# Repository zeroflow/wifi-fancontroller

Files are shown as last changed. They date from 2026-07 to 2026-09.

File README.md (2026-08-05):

# WiFi Fan Controller

**Smart fan control for your Home Assistant setup**

A CE-certified, ESP32-based PWM fan controller designed for home server racks, media cabinets, and smart home projects. Control up to 4 fans with temperature-based automation, remote monitoring, and seamless Home Assistant integration.

WiFi Fan Controller Board

## Why This Fan Controller?

**Intelligent Climate Control**: Automatically adjust fan speeds based on temperature and humidity readings from the integrated HDC1080 sensor. Turn fans off when equipment is idle, ramp up when things heat up.

**Home Assistant Native**: Built on ESPHome for seamless integration with Home Assistant. Monitor temperatures, adjust fan speeds, and create automations directly from your smart home dashboard.

**Hackable & Expandable**: Fully customizable ESPHome configuration with Qwiic and I2C expansion ports, NeoPixel output, user buttons, and GPIO breakouts. Add sensors, displays, or integrate with your existing projects.

**Professional Quality**: CE certified hardware with RGB status LEDs showing system status at a glance. Standard 12V DC barrel jack power input (5.5x2.1mm, centre positive).

## Get Your Board

**Ready to upgrade your setup?**

**[Buy on Elecrow - $35.99](https://www.elecrow.com/wifi-fancontroller1.html)** - Boards and 3D-printed cases available

**[Complete Documentation & Web Installer](https://fancontroller.arthofer.dev/)** - Flash firmware directly from your browser

**DIY Case**: Print your own case using the [WiFi Fancontroller Case](https://www.printables.com/model/987263-wifi-fancontroller-case) design on Printables.com.

## Power supply

The Fancontroller requires an external 12 V DC SELV power supply, not included.

* **Connector:** 5.5 × 2.1 mm barrel jack, centre positive
* **Voltage:** 12 V DC ±5 %
* **Current:** minimum 2.5 A recommended, depending on fan load

The power supply is not part of the product. Users must supply a power source that is certified for their region.

## RF exposure

This product contains a radio transmitter. Install the product so that a separation distance of at least 20 cm is maintained between the antenna and any person during normal operation. This product is not intended to be worn on the body or operated in close proximity to the user.

## User buttons

The board provides three user-assignable push buttons connected to GPIO. They have no function in the default configuration. Any behaviour is defined by the user's ESPHome configuration. Typical use is setup, commissioning, or occasional manual override; regular operation is via the network interface.

In the factory firmware the buttons are exposed to Home Assistant as binary sensors reporting their pressed state. They trigger no action on the board itself unless you configure one. See the [USR Buttons module](https://fancontroller.arthofer.dev/reference/modules/usr-buttons/) for one ready-made way to assign them.

## Specifications

* **Power**
  * External 12V DC SELV power supply, not included (see [Power supply](#power-supply))
  * 12V DC Barrel Input (5.5x2.1mm, centre positive)
  * Max total input current: 2.5A (set by the DC barrel jack -- applies to the sum of all fans plus board load, not per fan header)
  * Size your supply to the combined draw of the fans you connect, with headroom
  * Low power operation: 0.25W typical, 0.07W deep sleep
* **Fan Control**
  * 4× PWM Fan Outputs with RPM monitoring
  * Supports standard 12V 4-pin PWM fans
* **Sensors & I/O**
  * Integrated HDC1080 Temperature & Humidity Sensor
  * RGB Status LEDs for board and fan ports (Rev 3.x)
  * [Qwiic](https://www.sparkfun.com/qwiic) Expansion Port for easy sensor additions
  * I2C Expansion Port (2.54mm Header)
  * 5V NeoPixel Output Port
  * 3 User Buttons for custom functions
  * GPIO Expansion Pads (2.54mm SMD Header)
* **Connectivity**
  * WiFi (ESP32/ESP32-S2)
  * USB-C for programming and power (Rev 2.0+)

## Power Draw

The power usage of the device is dominated by the fans.
As a standalone device, these are the measured power figures in different operation modes.

Mode | Power Draw
---- | ----------
Active Wifi Transfer (e.g. OTA Upload) | 0.6W
Wifi connected, power save mode deactivated (not default) | 0.52W
```Default``` Wifi connected, LEDs showing status (one-colored) | 0.25W
Wifi connected, LEDs off | 0.2W
Deep Sleep | 0.07W

Disabling Wifi while not in deep sleep does not reduce power consumption, as the default light power save mode already does a good job.

These values have been measured via a DPS3005 power supply, therefore, their accuracy cannot be guaranteed.

---

## Quick Start

All boards come pre-flashed with an ESPHome factory image that's ready to use:

1. **Power up the board** via USB-C or 12V DC (USB-C is for flashing only, power via 12V DC barrel jack is required for fans)
2. **Connect to the WiFi hotspot** (e.g. `fancontroller-r3-1-abcdef`)
3. **Configure your WiFi** through the captive portal
4. **Done!** Board appears in Home Assistant via ESPHome

**What you get out of the box:**
The factory firmware exposes all 4 fan channels as speed controls in Home Assistant, along with temperature and humidity readings from the onboard sensor. Fan speeds can be adjusted manually from 0–100% or automated via Home Assistant. RPM monitoring is available for each fan port.

For custom firmware or troubleshooting, see [Installation Methods](#installation-methods) below.

### Identifying Your Board Revision

To choose the correct firmware, identify your board revision using the connectors:

Revision | Left                      | Fan Ports             | Right   | Details | Notes
---- | ----------------------------- | --------------------- | ------- | ------- | ------
1.0  | DC 12V                        | Fans                  | nothing | [Link](https://fancontroller.arthofer.dev/reference/hardware/rev-1-0/) |
2.0  | DC 12V, Status LED            | Fans                  | USB-C   | [Link](https://fancontroller.arthofer.dev/reference/hardware/rev-2-0/) |
3.0  | DC 12V, Status LED, QWIIC     | Fans                  | USB-C   | [Link](https://fancontroller.arthofer.dev/reference/hardware/rev-3-0/) |
3.1  | DC 12V, RGB Status LED, QWIIC | Fans, RGB Status LEDs | USB-C   | [Link](https://fancontroller.arthofer.dev/reference/hardware/rev-3-x/) |
3.2  | DC 12V, RGB Status LED, QWIIC | Fans, RGB Status LEDs | USB-C   | [Link](https://fancontroller.arthofer.dev/reference/hardware/rev-3-x/) | Compatible firmware and pinout - hardware-only revisions
3.3  | DC 12V, RGB Status LED, QWIIC | Fans, RGB Status LEDs | USB-C   | [Link](https://fancontroller.arthofer.dev/reference/hardware/rev-3-x/) | Compatible firmware and pinout - hardware-only revisions

---

## Installation Methods

### Method 1: Web Installer (Recommended)

Flash pre-built firmware directly from your browser at **[fancontroller.arthofer.dev](https://fancontroller.arthofer.dev/)**

Note for ESP32-S2 boards (Rev 2.0, 3.x): Web-based flashing may have connectivity issues. The most reliable web tool is [ESPWEBTOOL by Spacehuhn](https://esptool.spacehuhn.com/). If the browser flash fails, use Method 2 (esptool) instead.

### Method 2: esptool (Alternative for ESP32-S2)

Reliable flashing method, especially for ESP32-S2 boards:

1. Install [esptool](https://github.com/espressif/esptool): `pip install esptool`
2. Download prebuilt binary from [GitHub Releases](https://github.com/zeroflow/wifi-fancontroller/releases/)
3. Connect board via USB-C, hold BOOT button, press RESET
4. Flash: `esptool.py --chip esp32s2 write_flash 0x0 firmware.bin`
5. Press RESET to boot

### Method 3: OTA Updates (After Initial Setup)

Once connected to WiFi, update wirelessly via ESPHome dashboard or web interface at `http://[board-ip]`

### Method 4: ESPHome Hardware Packages (Custom Configurations)

For users who want to customize their configuration while keeping hardware setup simple. The hardware packages automatically configure all board-specific features for your revision.

This works by adding the following lines to your esphome config:

```yaml
# Import the hardware package for your board revision
packages:
  fancontroller: github://zeroflow/wifi-fancontroller/hardware-rev-3.3.yaml@main
```

#### Example Configuration

Here's a complete example showing how to create a custom configuration using the hardware package:

```yaml
# Import the hardware package for your board revision
packages:
  fancontroller: github://zeroflow/wifi-fancontroller/hardware-rev-3.3.yaml@main

esphome:
  name: my-fancontroller
  friendly_name: My Fan Controller

esp32:
  board: esp32-s2-saola-1  # Use esp32dev for Rev 1.0
  framework:
    type: arduino

# Enable logging
logger:

# Enable Home Assistant API
api:

# Enable OTA updates
ota:
  - platform: esphome

# Configure your WiFi
wifi:
  ssid: !secret wifi_ssid
  password: !secret wifi_password

  # Enable fallback hotspot
  ap: {}

captive_portal:
```

#### Available hardware packages:

- **Rev 1.0:** `hardware-rev-1.0.yaml` (ESP32, esp32dev board)
- **Rev 2.0:** `hardware-rev-2.0.yaml` (ESP32-S2, esp32-s2-saola-1 board)
- **Rev 3.0:** `hardware-rev-3.0.yaml` (ESP32-S2, esp32-s2-saola-1 board)
- **Rev 3.1, 3.2, 3.3:** `hardware-rev-3.3.yaml` (ESP32-S2, esp32-s2-saola-1 board)

#### What's Included in Hardware Packages

The hardware package automatically configures all board features:
- 4× PWM fan outputs with speed control and RPM monitoring
- HDC1080 temperature & humidity sensor
- User buttons (USR1, USR2, USR3) for custom functions
- Status LEDs (RGB on Rev 3.x)
- NeoPixel output port (Rev 3.x)
- WiFi signal strength sensor
- All expansion ports and GPIO

No manual pin configuration needed - just import the package and customize your automations!

---

<details>
<summary><strong>Fan Control Modules (advanced - click to expand)</strong></summary>

## Fan Control Modules

Beyond the basic hardware configuration, this project includes optional control modules that implement different fan control strategies. These modules can be imported into your configuration to add temperature-based fan control or status displays.

### Available Modules

#### 1. RPM Status LEDs (`modules/rpm_status_leds.yaml`)

Visual feedback module that updates each fan's RGB LED based on its RPM reading. LEDs sweep hue from red (stopped) through orange and yellow to green (full speed) using HSV color rotation, keeping the LED at full brightness at every point for vivid, easy-to-read colors.

**Configuration Variables:**
- `full_rpm`: Maximum RPM for color scaling (default: 2500). At 0 RPM = red, at full_rpm = green
- `brightness`: LED brightness 0.0–1.0 (default: 0.5)
- `update_interval`: LED update frequency (default: 1s)
- `fan1_led_enabled` … `fan4_led_enabled`: Enable/disable each LED individually (default: true)

**Example:**
```yaml
packages:
  rpm_status_leds:
    url: https://github.com/zeroflow/wifi-fancontroller
    ref: main
    files:
      - path: modules/rpm_status_leds.yaml
        vars:
          full_rpm: "2500"           # RPM value considered as 100% speed
          brightness: "0.3"          # Adjust for your environment
          fan3_led_enabled: "false"  # disable LED for unused fan channels
          fan4_led_enabled: "false"
```

#### 2. Linear Temperature Control (`modules/temperature_linear.yaml`)

Simple linear fan control based on temperature. Creates a temperature curve with three zones:
- Below t_off: Fans off (0%)
- Between t_off and t1: Constant speed at fanpercent1
- Between t1 and t2: Linear ramp from fanpercent1 to fanpercent2
- Above t2: Constant speed at fanpercent2

**Configuration Variables:**
- `friendly_name`: Device name prefix (default: "fancontroller")
- `t_off`: Temperature below which fans turn off (default: 25.0°C)
- `t1`: Lower temperature setpoint (default: 30.0°C)
- `t2`: Upper temperature setpoint (default: 50.0°C)
- `fanpercent1`: Fan speed % at t1 (default: 30.0%)
- `fanpercent2`: Fan speed % at t2 and above (default: 100.0%)

**Features:**
- Individual auto-control switches for each of 4 fans
- Output value sensor showing current calculated fan speed

**Example:**
```yaml
packages:
  temperature_linear:
    url: https://github.com/zeroflow/wifi-fancontroller
    files: 
      - path: modules/temperature_linear.yaml
        vars:
          friendly_name: "Server Rack"
          t_off: "25.0"        # Fans off below 25°C
          t1: "30.0"           # Start ramping at 30°C
          t2: "50.0"           # Full speed at 50°C
          fanpercent1: "30.0"  # Minimum speed: 30%
          fanpercent2: "100.0" # Maximum speed: 100%
```

#### 3. PID Temperature Control (`modules/temperature_pid.yaml`)

Advanced PID (Proportional-Integral-Derivative) control for precise temperature regulation. Automatically adjusts fan speeds to maintain a target temperature with minimal overshoot.

Shoutout to [patrickcollins12/esphome-fan-controller](https://github.com/patrickcollins12/esphome-fan-controller) for the example code.

A PID simulator is available at https://fancontroller.arthofer.dev/pid-simulator.
It uses simplified thermal models - treat results as a starting point for tuning.

**Configuration Variables:**
- `friendly_name`: Device name prefix (default: "fancontroller")
- `kp`: Proportional gain coefficient (default: 0.39509)
- `ki`: Integral gain coefficient (default: 0.00470)
- `kd`: Derivative gain coefficient (default: 20.74267)
- `max_integral`: Maximum integral term value (default: 0.0)
- `output_averaging_samples`: Output averaging samples (default: 1)
- `derivative_averaging_samples`: Derivative averaging samples (default: 5)

**Features:**
- Climate entity (thermostat) for Home Assistant integration
- Live PID tuning via Home Assistant number entities
- Auto-tune button for automatic PID parameter calculation
- Deadband control to reduce oscillation near target
- Manual override fan control
- Individual PID control switches for each of 4 fans
- Real-time monitoring of P, I, D terms and error values

**Example:**
```yaml
packages:
  temperature_pid:
    url: https://github.com/zeroflow/wifi-fancontroller
    files:
      - path: modules/temperature_pid.yaml
        vars:
          friendly_name: "Server Rack"
          kp: "0.39509"
          ki: "0.00470"
          kd: "20.74267"

```

**Tuning Tips:**
- Use the "PID Climate Autotune" button for automatic tuning
- Start with low kp/ki/kd values and increase gradually
- Monitor the P/I/D term sensors to understand controller behavior

#### 4. RPM PI Control (`modules/rpm_pi_control.yaml`)

PI (Proportional-Integral) controller that regulates PWM output to achieve and maintain precise target RPM for each fan. Unlike percentage-based control, this module uses closed-loop feedback to compensate for fan aging, voltage variations, and load changes.

**Important:** This module uses the existing fan speed sensors from the hardware package. Since the default hardware sensors update every 10s with heavy filtering (too slow for stable PI control), you **must override** the sensor definitions in your config to use faster updates (2s recommended) and minimal filtering. See the example configuration below.

**Configuration Variables:**
- `friendly_name`: Device name prefix (default: "fancontroller")
- `kp`: Proportional gain coefficient (default: 0.005)
- `ki`: Integral gain coefficient (default: 0.001)
- `update_interval`: Control loop update interval in seconds (default: 2, matches fast sensor update)

**Features:**
- Individual target RPM setpoints for each of 4 fans (0-4000 RPM range)
- Enable/disable PI control per fan with switches
- Live tuning of PI parameters via Home Assistant
- Real-time monitoring of error, P-term, I-term, and PWM output
- Anti-windup protection for integral term
- Configurable minimum PWM to prevent stalling
- Reset button for integral terms

**Example:**
```yaml
packages:
  hardware:
    url: https://github.com/zeroflow/wifi-fancontroller
    ref: main
    files: [hardware-rev-3.1.yaml]
  rpm_pi_control:
    url: https://github.com/zeroflow/wifi-fancontroller
    ref: main
    files: 
      - path: modules/rpm_pi_control.yaml
        vars:
          friendly_name: "Server Rack"
          kp: "0.005"           # Proportional gain
          ki: "0.001"           # Integral gain
          update_interval: "2s"  # Update every 2 seconds (matches sensor update)

# REQUIRED: Override hardware sensors for faster updates
sensor:
  - platform: pulse_counter
    id: fan1_speed
    pin: {number: GPIO16, mode: INPUT_PULLUP}
    update_interval: 2s
    filters:
      - multiply: 0.5
      - sliding_window_moving_average: {window_size: 3, send_every: 1}
  # Repeat for fan2_speed, fan3_speed, fan4_speed (see full example)
```

**How to Use:**
1. Enable "PI Control Fan X" switch in Home Assistant
2. Set "Fan X Target RPM" to your desired speed (e.g., 1500 RPM)
3. The controller automatically adjusts PWM to maintain that speed
4. Monitor debug sensors (Error, P-Term, I-Term, PWM Output) to verify operation
5. Fine-tune Kp and Ki parameters if needed

**Tuning Tips:**
- Start with small kp (0.003-0.01) and ki (0.0005-0.002) values
- If fans respond too slowly: Increase Kp
- If fans oscillate around target: Decrease Kp or Ki
- If there's persistent error (actual RPM stays below/above target): Increase Ki
- Use "Reset PI Integrators" button when changing parameters or after long idle periods
- Monitor the debug sensors to understand controller behavior

#### 5. Independent Triple Temperature Curves (`modules/temperature_curve_triple_independent.yaml`)

Three fully independent 5-point temperature curves, picked from Home Assistant with a "Curve Selection" select entity. Each profile carries its own temperature axis, its own speeds, **and its own source sensor**, so one profile can follow a heat pump flow temperature while another follows ambient room air. A profile whose speeds descend as temperature rises gives you an inverted curve, which is how you drive fans harder as water gets colder in cooling mode.

The sibling module `modules/temperature_curve_triple.yaml` shares one temperature axis across all three profiles. Use that one when the breakpoints stay fixed and only the aggressiveness changes; it does the job with 27 Home Assistant entities instead of 37.

**Configuration Variables:**
- `friendly_name`: Device name prefix (default: "Fancontroller")
- `curve_a_name` / `curve_b_name` / `curve_c_name`: Profile display names
- `curve_a_temp[1-5]` / `curve_b_temp[1-5]` / `curve_c_temp[1-5]`: Each profile's temperature axis, must be entered ascending
- `curve_a_speed[1-5]` / `curve_b_speed[1-5]` / `curve_c_speed[1-5]`: Each profile's speeds
- `curve_a_sensor_id` / `curve_b_sensor_id` / `curve_c_sensor_id`: ESPHome `id` of the sensor each profile reads (default: `fancontroller_temperature`, the onboard HDC1080)

**Features:**
- Three independent 5-point profiles, no shared state between them
- Per-profile source sensor, including `platform: homeassistant` sensors imported from Home Assistant
- Linear interpolation between points; no runtime sorting
- Selection dispatches on the select index, so renaming a profile cannot break which curve is active
- Individual auto-control switches for each of 4 fans
- Output value sensor showing the active profile's calculated fan speed
- Unordered axis on any profile raises a warning sensor and names the profile in the log, but forces the fans to 100% only while that profile is the active one
- An unavailable source sensor holds the last good reading for 60 seconds, then forces 100%

**Example:**
```yaml
packages:
  hardware:
    url: https://github.com/zeroflow/wifi-fancontroller
    ref: main
    files: [hardware-rev-3.1.yaml]
  temperature_curve_triple_independent:
    url: https://github.com/zeroflow/wifi-fancontroller
    ref: main
    files: [modules/temperature_curve_triple_independent.yaml]

# The sensors the profiles read, imported from Home Assistant
sensor:
  - platform: homeassistant
    id: hp_flow_temperature
    entity_id: sensor.heat_pump_flow_temperature
  - platform: homeassistant
    id: ambient_air_temperature
    entity_id: sensor.living_room_temperature

substitutions:
  curve_a_name: "Heating"
  curve_b_name: "Ventilation"
  curve_c_name: "Cooling"
  curve_a_sensor_id: "hp_flow_temperature"
  curve_b_sensor_id: "ambient_air_temperature"
  curve_c_sensor_id: "hp_flow_temperature"
  # Heating: flow temperature band, fans ramp up as the water gets hotter
  curve_a_temp1: "28.0"
  curve_a_temp5: "50.0"
  curve_a_speed1: "0.0"
  curve_a_speed5: "100.0"
  # Cooling: inverted. The AXIS still ascends, the SPEEDS descend.
  curve_c_temp1: "8.0"
  curve_c_temp5: "20.0"
  curve_c_speed1: "100.0"
  curve_c_speed5: "0.0"
  # ... points 2 to 4 omitted for brevity, see the full example
```

See [`examples/with-temperature-curve-triple-independent-rev-3.1.yaml`](examples/with-temperature-curve-triple-independent-rev-3.1.yaml) for a complete configuration.

**Important:** never invert the temperature axis to build an inverted curve. Enter the temperatures ascending and let the speeds descend. An unordered axis is treated as a fault, not as a feature.

A `curve_*_sensor_id` naming an `id` that does not exist fails at **compile** time, not at config validation, and the error is confusing: it surfaces as a C++ `'my_sensor' was not declared in this scope` pointing at generated code rather than at your YAML. Check the spelling of your sensor ids first if you see that. The value must be an ESPHome `id:`, not a Home Assistant `entity_id`.

### Choosing a Control Module

- **Linear Control**: Best for simple setups where you want predictable fan behavior based on temperature zones. Easy to understand and configure.
- **PID Temperature Control**: Best for precise temperature control and systems where you want to maintain a specific target temperature with minimal fluctuation.
- **Independent Triple Temperature Curves**: Best when one board has to serve several operating modes that differ in more than aggressiveness, for example a heat pump that heats in winter and cools in summer, or profiles that read different sensors.
- **RPM PI Control**: Best when you need precise fan speed control in RPM, regardless of temperature. Ideal for applications requiring consistent airflow, compensating for fan aging, or when you want to set exact fan speeds.
- **RPM Status LEDs**: Can be combined with any control module to add visual feedback.

You can combine multiple modules in your configuration. For example:
- Use PID temperature control with RPM status LEDs for precise temperature regulation with visual feedback
- Use RPM PI control with temperature sensors to create a custom automation that sets target RPM based on temperature thresholds
- Combine linear temperature control with RPM status LEDs for simple automatic control with visual feedback

</details>

---

## Ongoing Updates & Troubleshooting

**Over-the-Air Updates**: After initial setup, your board will appear in the ESPHome dashboard for wireless updates. No need to connect USB again.

**Troubleshooting Discovery Issues**: If your board doesn't appear in ESPHome after connecting to WiFi, check for mDNS issues on your network. You can work around this by manually specifying the board's IP address using the [manual_ip](https://esphome.io/components/wifi.html) configuration in your WiFi settings.

**Need Help?** Open an issue on [GitHub](https://github.com/zeroflow/wifi-fancontroller/issues) or consult the ESPHome documentation.

## Contributing

Found a bug or have a feature request? Open an issue or submit a pull request on [GitHub](https://github.com/zeroflow/wifi-fancontroller).

---

## License

**ESPHome configuration:** Copyright (C) 2026 Arthofer Engineering e.U.  
Licensed under the GNU General Public License v3.0 – see [LICENSE](LICENSE) for details.

**Hardware schematics (PDF):** (C) 2026 Arthofer Engineering e.U.  
All rights reserved. Provided for reference only.

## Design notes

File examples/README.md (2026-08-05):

# WiFi Fan Controller - Example Configurations

This directory contains example configurations showing how to use the hardware packages.

## Basic Examples

Simple configurations that get you started quickly:

- **`basic-rev-1.0.yaml`** - Minimal config for Hardware Revision 1.0 (ESP32)
- **`basic-rev-2.0.yaml`** - Minimal config for Hardware Revision 2.0 (ESP32-S2)
- **`basic-rev-3.0.yaml`** - Minimal config for Hardware Revision 3.0 (ESP32-S2)
- **`basic-rev-3.1.yaml`** - Minimal config for Hardware Revision 3.1 (ESP32-S2 with RGB LEDs)

## Advanced Examples

Examples showing additional features and modules:

- **`with-rpm-pi-control-rev-3.1.yaml`** - Shows how to use the RPM PI control module for precise fan speed regulation with deadband and I-term reset
- **`with-rgb-status-leds-rev-3.1.yaml`** - Shows how to use the RGB status LED module for visual fan speed feedback
- **`with-temperature-curve-rev-3.1.yaml`** - Shows how to use the temperature curve module for flexible multi-point fan control (recommended!)
- **`with-temperature-control-rev-3.1.yaml`** - Shows how to use temperature control modules (linear/PID) for automatic fan speed adjustment
- **`with-temperature-curve-external-sensor-rev-3.1.yaml`** - Shows how to drive the temperature curve from an external Qwiic BME680 instead of the onboard sensor, via `temperature_sensor_id`

## Usage

1. Copy one of the example files to your ESPHome configuration directory
2. Rename it to match your device (e.g., `my-fancontroller.yaml`)
3. Create a `secrets.yaml` file with your WiFi credentials:
   ```yaml
   wifi_ssid: "Your WiFi SSID"
   wifi_password: "Your WiFi Password"
   ```
4. Customize the configuration to your needs
5. Flash to your device using ESPHome

## Hardware Packages

All examples use hardware packages located in the root directory:

- `hardware-rev-1.0.yaml` - ESP32 board configuration
- `hardware-rev-2.0.yaml` - ESP32-S2 board configuration
- `hardware-rev-3.0.yaml` - ESP32-S2 with monochromatic status LED
- `hardware-rev-3.1.yaml` - ESP32-S2 with RGB status LEDs

## Optional Modules

Additional functionality can be added via modules in the `modules/` directory:

- `modules/rpm_pi_control.yaml` - PI controller for precise RPM regulation with deadband and I-term reset features
- `modules/rpm_status_leds.yaml` - Visual feedback for fan operation (RGB LEDs change color based on RPM)
- `modules/temperature_curve.yaml` - Flexible 5-point temperature curve with linear interpolation (recommended!)
- `modules/temperature_linear.yaml` - Simple linear temperature-based fan control
- `modules/temperature_pid.yaml` - PID-based temperature control for precise regulation

## Factory Images

For initial device flashing, use the factory images instead:

- `fancontroller-rev1.0-esp32.factory.yaml`
- `fancontroller-rev2.0-esp32s2.factory.yaml`
- `fancontroller-rev3.0-esp32s2.factory.yaml`
- `fancontroller-rev3.1-esp32s2.factory.yaml`

Factory images include additional provisioning features like improv_serial and are meant for first-time setup.

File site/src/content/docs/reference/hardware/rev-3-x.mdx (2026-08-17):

---
title: "Rev 3.x (3.1 / 3.2 / 3.3)"
description: Latest generation ESP32-S2 with RGB status LEDs, QWIIC expansion, and NeoPixel output
sidebar:
  label: Rev 3.x (3.1/3.2/3.3)
  order: 1
---

import FlashButton from '../../../../components/FlashButton.astro';
import { Aside, Tabs, TabItem } from '@astrojs/starlight/components';

The Rev 3.x series is the latest generation of the WiFi Fan Controller. All 3.1, 3.2, and 3.3 boards share identical firmware and pinout -- differences between sub-revisions are hardware-only improvements.

Key features over Rev 3.0: RGB status LEDs (SK6805) for board status and per-fan visual feedback.

## Hardware Package Import

Add this to your ESPHome config to import the hardware package for your board revision:

<Tabs>
  <TabItem label="Rev 3.3">
    ```yaml
    packages:
      hardware:
        url: https://github.com/zeroflow/wifi-fancontroller
        ref: main
        files: [hardware-rev-3.3.yaml]
    ```
  </TabItem>
  <TabItem label="Rev 3.2">
    ```yaml
    packages:
      hardware:
        url: https://github.com/zeroflow/wifi-fancontroller
        ref: main
        files: [hardware-rev-3.2.yaml]
    ```
  </TabItem>
  <TabItem label="Rev 3.1">
    ```yaml
    packages:
      hardware:
        url: https://github.com/zeroflow/wifi-fancontroller
        ref: main
        files: [hardware-rev-3.1.yaml]
    ```
  </TabItem>
</Tabs>

## Board Photos

### Rev 3.3

ESP32-S2 WiFi Fan Controller Rev 3.3 PCB front - 4 PWM fan headers, HDC1080 sensor, RGB LEDs, Qwiic port
ESP32-S2 WiFi Fan Controller Rev 3.3 PCB back - CE marking, SMD expansion pads

<details>
<summary>Rev 3.2</summary>

ESP32-S2 WiFi Fan Controller Rev 3.2 PCB front
ESP32-S2 WiFi Fan Controller Rev 3.2 PCB back

</details>

<details>
<summary>Rev 3.1</summary>

ESP32-S2 WiFi Fan Controller Rev 3.1 PCB - first revision with per-fan RGB status LEDs

</details>

## Specifications

- **MCU:** ESP32S2-Mini-2
- **Board platform:** esp32-s2-saola-1
- **Power:** external 12V DC SELV supply, not included (5.5x2.1mm barrel jack, centre positive, 12V DC ±5%)
- **Max total input current:** 2.5A (set by the DC barrel jack -- applies to the sum of all fans plus board electronics, not per fan header; size your supply to the combined draw of the fans you connect). See [Safety and Compliance](/reference/compliance/).
- **Flashing:** USB-C port
- **Fan outputs:** 4x PWM headers with signal buffering
- **Status LEDs:** SK6805 RGB LEDs for board status and each fan connector
- **Sensor:** HDC1080 Temperature and Humidity
- **Buttons:** Reset, Boot, 3x User
- **Expansion:** QWIIC I2C, I2C port (100mil), NeoPixel port (5V, max 2A), SMD expansion header

<Aside type="note" title="NeoPixel framework requirement">
The NeoPixel port on GPIO42 requires the `arduino` framework. The `esp32_rmt_led_strip` platform used for this pin does not work reliably with `esp-idf` on the ESP32-S2.
</Aside>

## Factory Firmware Installation

Select your board revision and click the button to flash the factory firmware directly from your browser via USB.

<Tabs>
  <TabItem label="Rev 3.3">
    <FlashButton manifest="/firmware/fancontroller-r3-3.manifest.json" label="Flash Rev 3.3 Factory Firmware" />
  </TabItem>
  <TabItem label="Rev 3.2">
    <FlashButton manifest="/firmware/fancontroller-r3-2.manifest.json" label="Flash Rev 3.2 Factory Firmware" />
  </TabItem>
  <TabItem label="Rev 3.1">
    <FlashButton manifest="/firmware/fancontroller-r3-1.manifest.json" label="Flash Rev 3.1 Factory Firmware" />
  </TabItem>
</Tabs>

<Aside type="caution" title="USB not working?">
The ESP32-S2 has known USB reliability issues. If the flash button doesn't detect your board:
1. Try a different USB cable (data cable, not charge-only)
2. Hold BOOT button while plugging in USB
3. Use [ESPWEBTOOL](https://esptool.spacehuhn.com/) as an alternative web flasher (flash binary at address 0x0)
4. As last resort, use `esptool.py` CLI: `esptool.py --chip esp32s2 write_flash 0x0 firmware.bin`

Download prebuilt binaries: [Rev 3.1](/firmware/fancontroller-r3-1-esp32s2.factory.bin) / [Rev 3.2](/firmware/fancontroller-r3-2-esp32s2.factory.bin) / [Rev 3.3](/firmware/fancontroller-r3-3-esp32s2.factory.bin)
</Aside>

<Aside type="caution" title="USB-C is for flashing only">
The USB-C port provides power to the ESP32-S2 microcontroller only. It cannot power the fans. Fans require an external 12V DC power supply connected to the DC input jack (5.5x2.1mm).
</Aside>

## Hardware Self-Test Firmware

Every board is tested with a QC firmware before it ships, and that same image is available here. It is a diagnostic build, not a usable controller firmware: it takes no WiFi credentials, joins no network and exposes nothing to Home Assistant. It exercises the hardware and reports the result through the onboard LEDs, so you can tell a genuine hardware fault from a configuration problem without attaching a serial console. Flash it if a fan channel, the sensor or a button seems dead and you want a second opinion before opening an issue.

<Aside type="caution" title="Run the test on USB power only">
Unplug the 12V supply and power the board from the USB-C port alone for the whole self test. The fan check asks you to bridge two pins on a fan header, and the pin right next to them carries the full 12V rail whenever the barrel jack is connected. USB power is all any of these checks need.
</Aside>

What it checks, and how to read it:

- **Fan channels.** Each PWM output runs at 1000 Hz and the tach input beside it reads that signal back. To test a channel, bridge pins 3 and 4 of its fan header, counting from the left, which shorts TACH to PWM. The LED for that header turns green while the bridge is in place and returns to red once you remove it. Repeat for each of the four headers.
- **Temperature and humidity sensor.** The board status LED shows dim purple on every valid HDC1080 reading, refreshed every 5 seconds. A status LED that stays dark means the sensor is not answering on the I2C bus.
- **User buttons.** Hold USR1 for a red status LED, USR2 for green, USR3 for blue. The LED goes dark on release and returns to the purple heartbeat.

<FlashButton manifest="/firmware/fancontroller-qc-r3-3.manifest.json" label="Flash QC Test Firmware (Rev 3.1 / 3.2 / 3.3)" />

The [config is in the repository](https://github.com/zeroflow/wifi-fancontroller/blob/main/fancontroller-rev3.3-esp32s2.qc.yaml) if you would rather read what it does before flashing it.

<Aside type="caution" title="This replaces the firmware on the board">
Flashing the QC image overwrites whatever is currently on the board, including your ESPHome config and its stored WiFi credentials. When you are done testing, flash the factory firmware above or your own ESPHome build to get back.
</Aside>

## ESP32-S2 Pin Assignment

This pin table applies to all Rev 3.1, 3.2, and 3.3 boards.

| Pin | Usage |
|---|---|
| GPIO0 | Boot Button, Push to enter flashing mode |
| GPIO1 | RGB Status LEDs, SK6805 (5 LEDs, ESPHome uses WS2812 driver, GRB color order) |
| GPIO2 | Expansion Header (Bottom) |
| GPIO3 | Expansion Header (Bottom) |
| GPIO4 | Expansion Header (Bottom) |
| GPIO5 | Expansion Header (Bottom) |
| GPIO6 | Expansion Header (Bottom) |
| GPIO7 | Expansion Header (Bottom) |
| GPIO8 | Expansion Header (Bottom) |
| GPIO9 | Expansion Header (Bottom) |
| GPIO10 | Expansion Header (Bottom) |
| GPIO11 | Expansion Header (Bottom) |
| GPIO12 | Fan 1 PWM |
| GPIO13 | Fan 2 PWM |
| GPIO14 | Fan 3 PWM |
| GPIO15 | Fan 4 PWM |
| GPIO16 | Fan 1 Speed Sense |
| GPIO17 | Fan 2 Speed Sense |
| GPIO18 | Fan 3 Speed Sense |
| GPIO21 | Fan 4 Speed Sense |
| GPIO26 | unused |
| GPIO33 | I2C SDA |
| GPIO34 | I2C SCL |
| GPIO35 | I2C INT |
| GPIO36 | USR3 |
| GPIO37 | USR2 |
| GPIO38 | USR1 |
| GPIO42 | Neopixel Expansion Port |
| GPIO43 | UART0 TX (U0TXD), Serial Flashing Header |
| GPIO44 | UART0 RX (U0RXD), Serial Flashing Header |
| GPIO45 | unused (strapping) |
| GPIO46 | unused (strapping) |

## Serial Flashing Header (TX/RX)

In addition to the USB-C port, the board exposes the ESP32-S2 UART0 on a serial header for flashing and serial logs. This is the fallback path when USB-C is not detected (see the USB troubleshooting note above) and the channel ESPHome's `logger` uses by default.

| Signal | Pin | Description |
|---|-----|---|
| 3.3V | 3.3V | |
| TX | GPIO43 | UART0 transmit (U0TXD), board to host |
| RX | GPIO44 | UART0 receive (U0RXD), host to board |
| GND | GND | Common ground (required for serial) |

Connect a 3.3V USB-to-serial adapter (TX to RX, RX to TX, GND to GND). To enter the bootloader for flashing, hold BOOT (GPIO0) while resetting the board.

<Aside type="caution" title="3.3V logic only">
The ESP32-S2 UART pins are 3.3V. Do not connect a 5V serial adapter directly to TX/RX.
</Aside>

## I2C Extension Port

The board offers an I2C extension port above Fan 4.

| Nr. | Pin | Description |
|-----|-----|---|
| 1 | GND | |
| 2 | INT | GPIO 35 |
| 3 | SCL | GPIO 34, 4.7k Pull-Up |
| 4 | SDA | GPIO 33, 4.7k Pull-Up |
| 5 | +3V3 | |

## Qwiic Connector

The board offers a Qwiic connector (standard JST-SH 4-pin, 1mm pitch) for solderless I2C expansion. It shares the **same I2C bus** as the 100mil I2C extension port and the onboard HDC1080 sensor, so addresses must not conflict across both ports.

| Nr. | Pin | Description |
|-----|-----|---|
| 1 | GND | Black wire |
| 2 | +3V3 | Red wire |
| 3 | SDA | GPIO 33, blue wire, 4.7k Pull-Up |
| 4 | SCL | GPIO 34, yellow wire, 4.7k Pull-Up |

<Aside type="note" title="Shared I2C bus">
The Qwiic port, the 100mil I2C extension port, and the onboard HDC1080 temperature/humidity sensor are all on the same I2C bus (GPIO33 SDA / GPIO34 SCL). Devices on any of these connectors share that bus.
</Aside>

## SMD Expansion Port

The board offers an SMD expansion port on the back.

| Nr. | Pin | Description |
|-----|-----|---|
| 1 | +3V3 | |
| 2 | +5V | |
| 3 | I/O | GPIO02 |
| 4 | I/O | GPIO03 |
| 5 | I/O | GPIO04 |
| 6 | I/O | GPIO05 |
| 7 | I/O | GPIO06 |
| 8 | I/O | GPIO07 |
| 9 | I/O | GPIO08 |
| 10 | I/O | GPIO09 |
| 11 | I/O | GPIO10 |
| 12 | I/O | GPIO11 |
| 13 | GND | |
| 14 | GND | |

## Example Configurations

### Basic Setup

- **[Rev 3.3 Basic](https://github.com/zeroflow/wifi-fancontroller/blob/main/examples/basic-rev-3.3.yaml)** -- Minimal setup with 4 fans
- **[Rev 3.2 Basic](https://github.com/zeroflow/wifi-fancontroller/blob/main/examples/basic-rev-3.2.yaml)** -- Minimal setup with 4 fans
- **[Rev 3.1 Basic](https://github.com/zeroflow/wifi-fancontroller/blob/main/examples/basic-rev-3.1.yaml)** -- Minimal setup with 4 fans

### Advanced Features

- **[RGB Status LEDs](https://github.com/zeroflow/wifi-fancontroller/blob/main/examples/with-rgb-status-leds-rev-3.1.yaml)** -- Visual fan speed feedback with color-coded LEDs (red=slow, green=fast)
- **[RPM PI Control](https://github.com/zeroflow/wifi-fancontroller/blob/main/examples/with-rpm-pi-control-rev-3.1.yaml)** -- Closed-loop RPM regulation per fan
- **[Temperature Control (Linear/PID)](https://github.com/zeroflow/wifi-fancontroller/blob/main/examples/with-temperature-control-rev-3.1.yaml)** -- Automatic fan speed adjustment based on temperature
- **[Temperature Curve](https://github.com/zeroflow/wifi-fancontroller/blob/main/examples/with-temperature-curve-rev-3.1.yaml)** -- Flexible 5-point temperature curve with linear interpolation

For all available examples, see the [examples directory](https://github.com/zeroflow/wifi-fancontroller/tree/main/examples).

## Revision History

All Rev 3.1, 3.2, and 3.3 boards share identical firmware and pinout. The differences between sub-revisions are hardware-only improvements:

| Revision | Changes |
|---|---|
| Rev 3.1 | Added RGB status LEDs (SK6805) for board + per-fan indication |
| Rev 3.2 | Improved USB-C fuse for better overcurrent protection |
| Rev 3.3 | Open-drain fan outputs, optimized component selection, enhanced power supply stability |

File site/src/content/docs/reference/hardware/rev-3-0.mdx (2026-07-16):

---
title: Rev 3.0
description: ESP32-S2 with Qwiic I2C, NeoPixel expansion, and PWM buffering
sidebar:
  order: 2
---

import FlashButton from '../../../../components/FlashButton.astro';
import { Aside } from '@astrojs/starlight/components';

Rev 3.0 added Qwiic I2C connectivity, a NeoPixel expansion port, PWM signal buffering for improved fan signal integrity, and a bottom SMD expansion header. Unlike Rev 3.1+, it does not have RGB status LEDs.

## Hardware Package Import

Add this to your ESPHome config to import the hardware package:

```yaml
packages:
  hardware:
    url: https://github.com/zeroflow/wifi-fancontroller
    ref: main
    files: [hardware-rev-3.0.yaml]
```

### Front

ESP32-S2 WiFi Fan Controller Rev 3.0 PCB front - Qwiic port, NeoPixel expansion, PWM buffering

### Back

ESP32-S2 WiFi Fan Controller Rev 3.0 PCB back - SMD expansion header

## Specifications

- **MCU:** ESP32S2-Mini-2
- **Board platform:** esp32-s2-saola-1
- **Power:** external 12V DC SELV supply, not included (5.5x2.1mm barrel jack, centre positive, 12V DC ±5%)
- **Max total input current:** 2.5A (set by the DC barrel jack -- applies to the sum of all fans plus board electronics, not per fan header; size your supply to the combined draw of the fans you connect). See [Safety and Compliance](/reference/compliance/).
- **Flashing:** USB-C port
- **Fan outputs:** 4x PWM headers with signal buffering
- **Status LED:** Red (single)
- **Sensor:** HDC1080 Temperature and Humidity
- **Buttons:** Reset, Boot, 3x User
- **Expansion:** QWIIC I2C, I2C port (100mil), NeoPixel port (5V, max 2A), SMD expansion header

<Aside type="note" title="NeoPixel framework requirement">
The NeoPixel port on GPIO42 requires the `arduino` framework. The `esp32_rmt_led_strip` platform used for this pin does not work reliably with `esp-idf` on the ESP32-S2.
</Aside>

## Factory Firmware Installation

<FlashButton manifest="/firmware/fancontroller-r3-0.manifest.json" label="Flash Rev 3.0 Factory Firmware" />

<Aside type="caution" title="USB not working?">
The ESP32-S2 has known USB reliability issues. If the flash button doesn't detect your board:
1. Try a different USB cable (data cable, not charge-only)
2. Hold BOOT button while plugging in USB
3. Use [ESPWEBTOOL](https://esptool.spacehuhn.com/) as an alternative web flasher (flash binary at address 0x0)
4. As last resort, use `esptool.py` CLI: `esptool.py --chip esp32s2 write_flash 0x0 firmware.bin`

[Download prebuilt binary](/firmware/fancontroller-r3-0-esp32s2.factory.bin)
</Aside>

<Aside type="caution" title="USB-C is for flashing only">
The USB-C port provides power to the ESP32-S2 microcontroller only. It cannot power the fans. Fans require an external 12V DC power supply connected to the DC input jack (5.5x2.1mm).
</Aside>

## ESP32-S2 Pin Assignment

| Pin | Usage |
|---|---|
| GPIO0 | Boot Button, Push to enter flashing mode |
| GPIO1 | Status LED (PWM-controlled, monochromatic with pulse effects) |
| GPIO2 | Expansion Header (Bottom) |
| GPIO3 | Expansion Header (Bottom) |
| GPIO4 | Expansion Header (Bottom) |
| GPIO5 | Expansion Header (Bottom) |
| GPIO6 | Expansion Header (Bottom) |
| GPIO7 | Expansion Header (Bottom) |
| GPIO8 | Expansion Header (Bottom) |
| GPIO9 | Expansion Header (Bottom) |
| GPIO10 | Expansion Header (Bottom) |
| GPIO11 | Expansion Header (Bottom) |
| GPIO12 | Fan 1 PWM |
| GPIO13 | Fan 2 PWM |
| GPIO14 | Fan 3 PWM |
| GPIO15 | Fan 4 PWM |
| GPIO16 | Fan 1 Speed Sense |
| GPIO17 | Fan 2 Speed Sense |
| GPIO18 | Fan 3 Speed Sense |
| GPIO21 | Fan 4 Speed Sense |
| GPIO26 | unused |
| GPIO33 | I2C SDA |
| GPIO34 | I2C SCL |
| GPIO35 | I2C INT |
| GPIO36 | USR3 |
| GPIO37 | USR2 |
| GPIO38 | USR1 |
| GPIO42 | Neopixel Expansion Port |
| GPIO45 | unused (strapping) |
| GPIO46 | unused (strapping) |

## I2C Extension Port

The board offers an I2C extension port above Fan 4.

| Nr. | Pin | Description |
|-----|-----|---|
| 1 | GND | |
| 2 | INT | GPIO 35 |
| 3 | SCL | GPIO 34, 4.7k Pull-Up |
| 4 | SDA | GPIO 33, 4.7k Pull-Up |
| 5 | +3V3 | |

## SMD Expansion Port

The board offers an SMD expansion port on the back.

| Nr. | Pin | Description |
|-----|-----|---|
| 1 | +3V3 | |
| 2 | +5V | |
| 3 | I/O | GPIO02 |
| 4 | I/O | GPIO03 |
| 5 | I/O | GPIO04 |
| 6 | I/O | GPIO05 |
| 7 | I/O | GPIO06 |
| 8 | I/O | GPIO07 |
| 9 | I/O | GPIO08 |
| 10 | I/O | GPIO09 |
| 11 | I/O | GPIO10 |
| 12 | I/O | GPIO11 |
| 13 | GND | |
| 14 | GND | |

## Example Configurations

- **[Basic Configuration](https://github.com/zeroflow/wifi-fancontroller/blob/main/examples/basic-rev-3.0.yaml)** -- Minimal setup with 4 fans and essential features

For more examples, see the [examples directory](https://github.com/zeroflow/wifi-fancontroller/tree/main/examples).

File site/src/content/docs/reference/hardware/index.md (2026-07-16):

---
title: Hardware Revisions
description: Overview and comparison of WiFi Fan Controller hardware revisions
sidebar:
  label: Overview
  order: 0
---

The WiFi Fan Controller has gone through several hardware revisions, each replacing the previous generation. All revisions share the same core features -- 4 PWM fan headers, an HDC1080 temperature and humidity sensor, and ESPHome-based firmware with Home Assistant integration.

The **current revision is Rev 3.3**. Earlier revisions are documented here for existing owners.

## Revision Comparison

| Feature | Rev 1.0 | Rev 2.0 | Rev 3.0 | Rev 3.x (3.1/3.2/3.3) |
|---|---|---|---|---|
| MCU | ESP32 | ESP32-S2 | ESP32-S2 | ESP32-S2 |
| Board | esp32dev | esp32-s2-saola-1 | esp32-s2-saola-1 | esp32-s2-saola-1 |
| Flashing | Serial header | USB-C | USB-C | USB-C |
| Status LED | Red (single) | Red (single) | Red (single) | RGB (SK6805) x5 |
| Expansion | I2C + 2x ext input | I2C | QWIIC + I2C + NeoPixel | QWIIC + I2C + NeoPixel |
| PWM buffering | No | No | Yes | Yes |
| Fan connectors | 4x PWM | 4x PWM | 4x PWM | 4x PWM |
| Sensor | HDC1080 | HDC1080 | HDC1080 | HDC1080 |

## Revisions

- **[Rev 3.x (3.1 / 3.2 / 3.3)](/reference/hardware/rev-3-x/)** -- Current generation with RGB status LEDs, QWIIC expansion, and NeoPixel output. All three sub-revisions share identical firmware and pinout.
- **[Rev 3.0](/reference/hardware/rev-3-0/)** -- Added QWIIC I2C, NeoPixel expansion, and PWM buffering. No RGB status LEDs. Replaced by Rev 3.1.
- **[Rev 2.0](/reference/hardware/rev-2-0/)** -- Introduced USB-C flashing with ESP32-S2. Replaced by Rev 3.0.
- **[Rev 1.0](/reference/hardware/rev-1-0/)** -- Original ESP32 design with serial flashing. Replaced by Rev 2.0.

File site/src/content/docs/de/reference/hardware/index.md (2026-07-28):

---
title: Hardware-Revisionen
description: Übersicht und Vergleich der WiFi Lüftersteuerung Hardware-Revisionen
sidebar:
  label: Übersicht
  order: 0
---

Die WiFi Lüftersteuerung hat mehrere Hardware-Revisionen durchlaufen, wobei jede die vorherige Generation abgelöst hat. Alle Revisionen teilen sich die gleichen Kernfunktionen: 4 PWM-Lüfteranschlüsse, einen HDC1080 Temperatur- und Luftfeuchtigkeitssensor sowie ESPHome-basierte Firmware mit Home Assistant-Integration.

Die **aktuelle Revision ist Rev 3.3**. Frühere Revisionen sind hier für bestehende Besitzerinnen und Besitzer dokumentiert.

## Revisionsvergleich

| Merkmal | Rev 1.0 | Rev 2.0 | Rev 3.0 | Rev 3.x (3.1/3.2/3.3) |
|---|---|---|---|---|
| MCU | ESP32 | ESP32-S2 | ESP32-S2 | ESP32-S2 |
| Board | esp32dev | esp32-s2-saola-1 | esp32-s2-saola-1 | esp32-s2-saola-1 |
| Flashen | Serieller Header | USB-C | USB-C | USB-C |
| Status-LED | Rot (einzeln) | Rot (einzeln) | Rot (einzeln) | RGB (SK6805) x5 |
| Erweiterung | I2C + 2x ext. Eingang | I2C | QWIIC + I2C + NeoPixel | QWIIC + I2C + NeoPixel |
| PWM-Pufferung | Nein | Nein | Ja | Ja |
| Lüfteranschlüsse | 4x PWM | 4x PWM | 4x PWM | 4x PWM |
| Sensor | HDC1080 | HDC1080 | HDC1080 | HDC1080 |

## Revisionen

- **[Rev 3.x (3.1 / 3.2 / 3.3)](/de/reference/hardware/rev-3-x/)**: Aktuelle Generation mit RGB-Status-LEDs, QWIIC-Erweiterung und NeoPixel-Ausgang. Alle drei Unterrevisionen teilen sich identische Firmware und Pin-Belegung.
- **[Rev 3.0](/de/reference/hardware/rev-3-0/)**: Ergänzte QWIIC I2C, NeoPixel-Erweiterung und PWM-Pufferung. Keine RGB-Status-LEDs. Abgelöst durch Rev 3.1.
- **[Rev 2.0](/de/reference/hardware/rev-2-0/)**: Führte USB-C-Flashing mit ESP32-S2 ein. Abgelöst durch Rev 3.0.
- **[Rev 1.0](/de/reference/hardware/rev-1-0/)**: Ursprüngliches ESP32-Design mit seriellem Flashen. Abgelöst durch Rev 2.0.

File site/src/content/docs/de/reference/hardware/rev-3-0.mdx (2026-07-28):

---
title: Rev 3.0
description: ESP32-S2 mit Qwiic I2C, NeoPixel-Erweiterung und PWM-Pufferung
sidebar:
  order: 2
---

import FlashButton from '../../../../../components/FlashButton.astro';
import { Aside } from '@astrojs/starlight/components';

Rev 3.0 ergänzte Qwiic-I2C-Konnektivität, einen NeoPixel-Erweiterungsport, PWM-Signalpufferung für eine verbesserte Signalintegrität der Lüfter und einen SMD-Erweiterungsheader auf der Unterseite. Im Gegensatz zu Rev 3.1+ verfügt sie nicht über RGB-Status-LEDs.

## Import des Hardware-Pakets

Fügen Sie Folgendes zu Ihrer ESPHome-Konfiguration hinzu, um das Hardware-Paket zu importieren:

```yaml
packages:
  hardware:
    url: https://github.com/zeroflow/wifi-fancontroller
    ref: main
    files: [hardware-rev-3.0.yaml]
```

### Vorderseite

ESP32-S2 WiFi Lüftersteuerung Rev 3.0 Platine Vorderseite - Qwiic-Port, NeoPixel-Erweiterung, PWM-Pufferung

### Rückseite

ESP32-S2 WiFi Lüftersteuerung Rev 3.0 Platine Rückseite - SMD-Erweiterungsheader

## Spezifikationen

- **MCU:** ESP32S2-Mini-2
- **Board-Plattform:** esp32-s2-saola-1
- **Stromversorgung:** externes 12 V DC SELV-Netzteil, nicht im Lieferumfang enthalten (Hohlstecker 5,5 x 2,1 mm, Mittelpin positiv, 12 V DC ±5 %)
- **Maximaler Gesamteingangsstrom:** 2,5 A (festgelegt durch die DC-Hohlbuchse; gilt für die Summe aller Lüfter zuzüglich der Platinenelektronik und beschreibt keinen Grenzwert für einen einzelnen Lüfteranschluss; dimensionieren Sie Ihr Netzteil mit Reserve für die kombinierte Leistungsaufnahme der angeschlossenen Lüfter). Siehe [Sicherheit und Konformität](/de/reference/compliance/).
- **Flashen:** USB-C-Port
- **Lüfterausgänge:** 4x PWM-Header mit Signalpufferung
- **Status-LED:** Rot (einzeln)
- **Sensor:** HDC1080 Temperatur und Luftfeuchtigkeit
- **Taster:** Reset, Boot, 3x Benutzer
- **Erweiterung:** QWIIC I2C, I2C-Port (100mil), NeoPixel-Port (5V, max 2A), SMD-Erweiterungsheader

<Aside type="note" title="NeoPixel-Framework-Anforderung">
Der NeoPixel-Port an GPIO42 erfordert das `arduino`-Framework. Die für diesen Pin verwendete Plattform `esp32_rmt_led_strip` funktioniert unter `esp-idf` auf dem ESP32-S2 nicht zuverlässig.
</Aside>

## Werksfirmware-Installation

<FlashButton manifest="/firmware/fancontroller-r3-0.manifest.json" label="Rev 3.0 Werksfirmware flashen" />

<Aside type="caution" title="USB funktioniert nicht?">
Der ESP32-S2 hat bekannte USB-Zuverlässigkeitsprobleme. Falls die Flash-Schaltfläche Ihre Platine nicht erkennt:
1. Probieren Sie ein anderes USB-Kabel (Datenkabel, kein reines Ladekabel)
2. Halten Sie die BOOT-Taste gedrückt, während Sie USB einstecken
3. Nutzen Sie [ESPWEBTOOL](https://esptool.spacehuhn.com/) als alternativen Web-Flasher (Firmware-Binary an Adresse 0x0 flashen)
4. Als letzten Ausweg nutzen Sie die `esptool.py`-CLI: `esptool.py --chip esp32s2 write_flash 0x0 firmware.bin`

[Vorgefertigte Binärdatei herunterladen](/firmware/fancontroller-r3-0-esp32s2.factory.bin)
</Aside>

<Aside type="caution" title="USB-C dient nur dem Flashen">
Der USB-C-Anschluss versorgt ausschließlich den ESP32-S2-Mikrocontroller mit Strom. Er kann die Lüfter nicht mit Strom versorgen. Lüfter benötigen ein externes 12 V DC-Netzteil, angeschlossen an die DC-Eingangsbuchse (5,5 x 2,1 mm).
</Aside>

## ESP32-S2 Pin-Belegung

| Pin | Verwendung |
|---|---|
| GPIO0 | Boot-Taster, drücken um in den Flashing-Modus zu wechseln |
| GPIO1 | Status-LED (PWM-gesteuert, monochrom mit Pulseffekten) |
| GPIO2 | Erweiterungsheader (Unterseite) |
| GPIO3 | Erweiterungsheader (Unterseite) |
| GPIO4 | Erweiterungsheader (Unterseite) |
| GPIO5 | Erweiterungsheader (Unterseite) |
| GPIO6 | Erweiterungsheader (Unterseite) |
| GPIO7 | Erweiterungsheader (Unterseite) |
| GPIO8 | Erweiterungsheader (Unterseite) |
| GPIO9 | Erweiterungsheader (Unterseite) |
| GPIO10 | Erweiterungsheader (Unterseite) |
| GPIO11 | Erweiterungsheader (Unterseite) |
| GPIO12 | Fan 1 PWM |
| GPIO13 | Fan 2 PWM |
| GPIO14 | Fan 3 PWM |
| GPIO15 | Fan 4 PWM |
| GPIO16 | Fan 1 Drehzahlerfassung |
| GPIO17 | Fan 2 Drehzahlerfassung |
| GPIO18 | Fan 3 Drehzahlerfassung |
| GPIO21 | Fan 4 Drehzahlerfassung |
| GPIO26 | unbenutzt |
| GPIO33 | I2C SDA |
| GPIO34 | I2C SCL |
| GPIO35 | I2C INT |
| GPIO36 | USR3 |
| GPIO37 | USR2 |
| GPIO38 | USR1 |
| GPIO42 | Neopixel-Erweiterungsport |
| GPIO45 | unbenutzt (Strapping) |
| GPIO46 | unbenutzt (Strapping) |

## I2C-Erweiterungsport

Die Platine bietet einen I2C-Erweiterungsport oberhalb von Fan 4.

| Nr. | Pin | Beschreibung |
|-----|-----|---|
| 1 | GND | |
| 2 | INT | GPIO 35 |
| 3 | SCL | GPIO 34, 4,7k Pull-Up |
| 4 | SDA | GPIO 33, 4,7k Pull-Up |
| 5 | +3V3 | |

## SMD-Erweiterungsport

Die Platine bietet einen SMD-Erweiterungsport auf der Rückseite.

| Nr. | Pin | Beschreibung |
|-----|-----|---|
| 1 | +3V3 | |
| 2 | +5V | |
| 3 | I/O | GPIO02 |
| 4 | I/O | GPIO03 |
| 5 | I/O | GPIO04 |
| 6 | I/O | GPIO05 |
| 7 | I/O | GPIO06 |
| 8 | I/O | GPIO07 |
| 9 | I/O | GPIO08 |
| 10 | I/O | GPIO09 |
| 11 | I/O | GPIO10 |
| 12 | I/O | GPIO11 |
| 13 | GND | |
| 14 | GND | |

## Beispielkonfigurationen

- **[Grundkonfiguration](https://github.com/zeroflow/wifi-fancontroller/blob/main/examples/basic-rev-3.0.yaml)**: Minimales Setup mit 4 Lüftern und den wichtigsten Funktionen

Weitere Beispiele finden Sie im [Beispielverzeichnis](https://github.com/zeroflow/wifi-fancontroller/tree/main/examples).

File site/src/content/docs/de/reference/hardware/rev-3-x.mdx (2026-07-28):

---
title: "Rev 3.x (3.1 / 3.2 / 3.3)"
description: Neueste Generation ESP32-S2 mit RGB-Status-LEDs, QWIIC-Erweiterung und NeoPixel-Ausgang
sidebar:
  label: Rev 3.x (3.1/3.2/3.3)
  order: 1
---

import FlashButton from '../../../../../components/FlashButton.astro';
import { Aside, Tabs, TabItem } from '@astrojs/starlight/components';

Die Rev 3.x-Serie ist die aktuelle Generation der WiFi Lüftersteuerung. Alle 3.1-, 3.2- und 3.3-Platinen teilen sich identische Firmware und Pin-Belegung. Unterschiede zwischen den Unterrevisionen betreffen ausschließlich hardwareseitige Verbesserungen.

Wichtige Merkmale gegenüber Rev 3.0: RGB-Status-LEDs (SK6805) für Platinenstatus und visuelle Rückmeldung pro Lüfter.

## Import des Hardware-Pakets

Fügen Sie Folgendes zu Ihrer ESPHome-Konfiguration hinzu, um das Hardware-Paket für Ihre Platinenrevision zu importieren:

<Tabs>
  <TabItem label="Rev 3.3">
    ```yaml
    packages:
      hardware:
        url: https://github.com/zeroflow/wifi-fancontroller
        ref: main
        files: [hardware-rev-3.3.yaml]
    ```
  </TabItem>
  <TabItem label="Rev 3.2">
    ```yaml
    packages:
      hardware:
        url: https://github.com/zeroflow/wifi-fancontroller
        ref: main
        files: [hardware-rev-3.2.yaml]
    ```
  </TabItem>
  <TabItem label="Rev 3.1">
    ```yaml
    packages:
      hardware:
        url: https://github.com/zeroflow/wifi-fancontroller
        ref: main
        files: [hardware-rev-3.1.yaml]
    ```
  </TabItem>
</Tabs>

## Platinenfotos

### Rev 3.3

ESP32-S2 WiFi Lüftersteuerung Rev 3.3 Platine Vorderseite - 4 PWM-Lüfteranschlüsse, HDC1080-Sensor, RGB-LEDs, Qwiic-Port
ESP32-S2 WiFi Lüftersteuerung Rev 3.3 Platine Rückseite - CE-Kennzeichnung, SMD-Erweiterungspads

<details>
<summary>Rev 3.2</summary>

ESP32-S2 WiFi Lüftersteuerung Rev 3.2 Platine Vorderseite
ESP32-S2 WiFi Lüftersteuerung Rev 3.2 Platine Rückseite

</details>

<details>
<summary>Rev 3.1</summary>

ESP32-S2 WiFi Lüftersteuerung Rev 3.1 Platine - erste Revision mit RGB-Status-LEDs pro Lüfter

</details>

## Spezifikationen

- **MCU:** ESP32S2-Mini-2
- **Board-Plattform:** esp32-s2-saola-1
- **Stromversorgung:** externes 12 V DC SELV-Netzteil, nicht im Lieferumfang enthalten (Hohlstecker 5,5 x 2,1 mm, Mittelpin positiv, 12 V DC ±5 %)
- **Maximaler Gesamteingangsstrom:** 2,5 A (festgelegt durch die DC-Hohlbuchse; gilt für die Summe aller Lüfter zuzüglich der Platinenelektronik und beschreibt keinen Grenzwert für einen einzelnen Lüfteranschluss; dimensionieren Sie Ihr Netzteil mit Reserve für die kombinierte Leistungsaufnahme der angeschlossenen Lüfter). Siehe [Sicherheit und Konformität](/de/reference/compliance/).
- **Flashen:** USB-C-Port
- **Lüfterausgänge:** 4x PWM-Header mit Signalpufferung
- **Status-LEDs:** SK6805 RGB-LEDs für Platinenstatus und pro Lüfter
- **Sensor:** HDC1080 Temperatur und Luftfeuchtigkeit
- **Taster:** Reset, Boot, 3x Benutzer
- **Erweiterung:** QWIIC I2C, I2C-Port (100mil), NeoPixel-Port (5V, max 2A), SMD-Erweiterungsheader

<Aside type="note" title="NeoPixel-Framework-Anforderung">
Der NeoPixel-Port an GPIO42 erfordert das `arduino`-Framework. Die für diesen Pin verwendete Plattform `esp32_rmt_led_strip` funktioniert unter `esp-idf` auf dem ESP32-S2 nicht zuverlässig.
</Aside>

## Werksfirmware-Installation

Wählen Sie Ihre Platinenrevision und klicken Sie auf die Schaltfläche, um die Werksfirmware direkt aus Ihrem Browser über USB zu flashen.

<Tabs>
  <TabItem label="Rev 3.3">
    <FlashButton manifest="/firmware/fancontroller-r3-3.manifest.json" label="Rev 3.3 Werksfirmware flashen" />
  </TabItem>
  <TabItem label="Rev 3.2">
    <FlashButton manifest="/firmware/fancontroller-r3-2.manifest.json" label="Rev 3.2 Werksfirmware flashen" />
  </TabItem>
  <TabItem label="Rev 3.1">
    <FlashButton manifest="/firmware/fancontroller-r3-1.manifest.json" label="Rev 3.1 Werksfirmware flashen" />
  </TabItem>
</Tabs>

<Aside type="caution" title="USB funktioniert nicht?">
Der ESP32-S2 hat bekannte USB-Zuverlässigkeitsprobleme. Falls die Flash-Schaltfläche Ihre Platine nicht erkennt:
1. Probieren Sie ein anderes USB-Kabel (Datenkabel, kein reines Ladekabel)
2. Halten Sie die BOOT-Taste gedrückt, während Sie USB einstecken
3. Nutzen Sie [ESPWEBTOOL](https://esptool.spacehuhn.com/) als alternativen Web-Flasher (Firmware-Binary an Adresse 0x0 flashen)
4. Als letzten Ausweg nutzen Sie die `esptool.py`-CLI: `esptool.py --chip esp32s2 write_flash 0x0 firmware.bin`

Vorgefertigte Binärdateien herunterladen: [Rev 3.1](/firmware/fancontroller-r3-1-esp32s2.factory.bin) / [Rev 3.2](/firmware/fancontroller-r3-2-esp32s2.factory.bin) / [Rev 3.3](/firmware/fancontroller-r3-3-esp32s2.factory.bin)
</Aside>

<Aside type="caution" title="USB-C dient nur dem Flashen">
Der USB-C-Anschluss versorgt ausschließlich den ESP32-S2-Mikrocontroller mit Strom. Er kann die Lüfter nicht mit Strom versorgen. Lüfter benötigen ein externes 12 V DC-Netzteil, angeschlossen an die DC-Eingangsbuchse (5,5 x 2,1 mm).
</Aside>

## ESP32-S2 Pin-Belegung

Diese Pin-Tabelle gilt für alle Rev 3.1-, 3.2- und 3.3-Platinen.

| Pin | Verwendung |
|---|---|
| GPIO0 | Boot-Taster, drücken um in den Flashing-Modus zu wechseln |
| GPIO1 | RGB-Status-LEDs, SK6805 (5 LEDs, ESPHome nutzt den WS2812-Treiber, GRB-Farbreihenfolge) |
| GPIO2 | Erweiterungsheader (Unterseite) |
| GPIO3 | Erweiterungsheader (Unterseite) |
| GPIO4 | Erweiterungsheader (Unterseite) |
| GPIO5 | Erweiterungsheader (Unterseite) |
| GPIO6 | Erweiterungsheader (Unterseite) |
| GPIO7 | Erweiterungsheader (Unterseite) |
| GPIO8 | Erweiterungsheader (Unterseite) |
| GPIO9 | Erweiterungsheader (Unterseite) |
| GPIO10 | Erweiterungsheader (Unterseite) |
| GPIO11 | Erweiterungsheader (Unterseite) |
| GPIO12 | Fan 1 PWM |
| GPIO13 | Fan 2 PWM |
| GPIO14 | Fan 3 PWM |
| GPIO15 | Fan 4 PWM |
| GPIO16 | Fan 1 Drehzahlerfassung |
| GPIO17 | Fan 2 Drehzahlerfassung |
| GPIO18 | Fan 3 Drehzahlerfassung |
| GPIO21 | Fan 4 Drehzahlerfassung |
| GPIO26 | unbenutzt |
| GPIO33 | I2C SDA |
| GPIO34 | I2C SCL |
| GPIO35 | I2C INT |
| GPIO36 | USR3 |
| GPIO37 | USR2 |
| GPIO38 | USR1 |
| GPIO42 | Neopixel-Erweiterungsport |
| GPIO43 | UART0 TX (U0TXD), serieller Flashing-Header |
| GPIO44 | UART0 RX (U0RXD), serieller Flashing-Header |
| GPIO45 | unbenutzt (Strapping) |
| GPIO46 | unbenutzt (Strapping) |

## Serieller Flashing-Header (TX/RX)

Zusätzlich zum USB-C-Port stellt die Platine den ESP32-S2 UART0 auf einem seriellen Header für Flashen und serielle Logs bereit. Dies ist der Ausweichpfad, wenn USB-C nicht erkannt wird (siehe den USB-Fehlerbehebungshinweis oben), und der Kanal, den ESPHomes `logger` standardmäßig verwendet.

| Signal | Pin | Beschreibung |
|---|-----|---|
| 3.3V | 3.3V | |
| TX | GPIO43 | UART0 Sende-Leitung (U0TXD), Platine an Host |
| RX | GPIO44 | UART0 Empfangs-Leitung (U0RXD), Host an Platine |
| GND | GND | Gemeinsame Masse (für seriell erforderlich) |

Verbinden Sie einen 3,3 V USB-zu-Seriell-Adapter (TX zu RX, RX zu TX, GND zu GND). Um den Bootloader zum Flashen aufzurufen, halten Sie BOOT (GPIO0) gedrückt, während Sie die Platine zurücksetzen.

<Aside type="caution" title="Nur 3,3V-Logikpegel">
Die UART-Pins des ESP32-S2 arbeiten mit 3,3 V. Schließen Sie keinen 5V-Seriell-Adapter direkt an TX/RX an.
</Aside>

## I2C-Erweiterungsport

Die Platine bietet einen I2C-Erweiterungsport oberhalb von Fan 4.

| Nr. | Pin | Beschreibung |
|-----|-----|---|
| 1 | GND | |
| 2 | INT | GPIO 35 |
| 3 | SCL | GPIO 34, 4,7k Pull-Up |
| 4 | SDA | GPIO 33, 4,7k Pull-Up |
| 5 | +3V3 | |

## Qwiic-Anschluss

Die Platine bietet einen Qwiic-Anschluss (Standard JST-SH 4-Pin, 1mm Raster) für lötfreie I2C-Erweiterung. Er teilt sich denselben **I2C-Bus** wie der 100mil I2C-Erweiterungsport und den onboard HDC1080-Sensor, daher dürfen Adressen über beide Ports hinweg nicht kollidieren.

| Nr. | Pin | Beschreibung |
|-----|-----|---|
| 1 | GND | Schwarzes Kabel |
| 2 | +3V3 | Rotes Kabel |
| 3 | SDA | GPIO 33, blaues Kabel, 4,7k Pull-Up |
| 4 | SCL | GPIO 34, gelbes Kabel, 4,7k Pull-Up |

<Aside type="note" title="Gemeinsamer I2C-Bus">
Der Qwiic-Port, der 100mil I2C-Erweiterungsport und der onboard Temperatur-/Luftfeuchtigkeitssensor HDC1080 liegen alle auf demselben I2C-Bus (GPIO33 SDA / GPIO34 SCL). Geräte an jedem dieser Anschlüsse teilen sich diesen Bus.
</Aside>

## SMD-Erweiterungsport

Die Platine bietet einen SMD-Erweiterungsport auf der Rückseite.

| Nr. | Pin | Beschreibung |
|-----|-----|---|
| 1 | +3V3 | |
| 2 | +5V | |
| 3 | I/O | GPIO02 |
| 4 | I/O | GPIO03 |
| 5 | I/O | GPIO04 |
| 6 | I/O | GPIO05 |
| 7 | I/O | GPIO06 |
| 8 | I/O | GPIO07 |
| 9 | I/O | GPIO08 |
| 10 | I/O | GPIO09 |
| 11 | I/O | GPIO10 |
| 12 | I/O | GPIO11 |
| 13 | GND | |
| 14 | GND | |

## Beispielkonfigurationen

### Grund-Setup

- **[Rev 3.3 Grundkonfiguration](https://github.com/zeroflow/wifi-fancontroller/blob/main/examples/basic-rev-3.3.yaml)**: Minimales Setup mit 4 Lüftern
- **[Rev 3.2 Grundkonfiguration](https://github.com/zeroflow/wifi-fancontroller/blob/main/examples/basic-rev-3.2.yaml)**: Minimales Setup mit 4 Lüftern
- **[Rev 3.1 Grundkonfiguration](https://github.com/zeroflow/wifi-fancontroller/blob/main/examples/basic-rev-3.1.yaml)**: Minimales Setup mit 4 Lüftern

### Erweiterte Funktionen

- **[RGB-Status-LEDs](https://github.com/zeroflow/wifi-fancontroller/blob/main/examples/with-rgb-status-leds-rev-3.1.yaml)**: Visuelle Rückmeldung der Lüfterdrehzahl mit farbcodierten LEDs (rot=langsam, grün=schnell)
- **[RPM PI-Regelung](https://github.com/zeroflow/wifi-fancontroller/blob/main/examples/with-rpm-pi-control-rev-3.1.yaml)**: Geschlossene Drehzahlregelung pro Lüfter
- **[Temperaturregelung (Linear/PID)](https://github.com/zeroflow/wifi-fancontroller/blob/main/examples/with-temperature-control-rev-3.1.yaml)**: Automatische Anpassung der Lüfterdrehzahl basierend auf der Temperatur
- **[Temperaturkurve](https://github.com/zeroflow/wifi-fancontroller/blob/main/examples/with-temperature-curve-rev-3.1.yaml)**: Flexible 5-Punkte-Temperaturkurve mit linearer Interpolation

Alle verfügbaren Beispiele finden Sie im [Beispielverzeichnis](https://github.com/zeroflow/wifi-fancontroller/tree/main/examples).

## Revisionsverlauf

Alle Rev 3.1-, 3.2- und 3.3-Platinen teilen sich identische Firmware und Pin-Belegung. Die Unterschiede zwischen den Unterrevisionen betreffen ausschließlich hardwareseitige Verbesserungen:

| Revision | Änderungen |
|---|---|
| Rev 3.1 | RGB-Status-LEDs (SK6805) für Platine + Rückmeldung pro Lüfter hinzugefügt |
| Rev 3.2 | Verbesserte USB-C-Sicherung für besseren Überstromschutz |
| Rev 3.3 | Open-Drain-Lüfterausgänge, optimierte Bauteilauswahl, verbesserte Stabilität der Stromversorgung |

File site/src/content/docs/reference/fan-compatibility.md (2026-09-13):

---
title: Fan Compatibility
description: Which fans spin down to 0 RPM, how to check a fan that is not listed, and community-reported behavior at low PWM duty cycles
---

## Connector Compatibility

The controller uses standard 4-pin PWM fan headers. Fan type determines what is possible before any speed control is considered:

| Fan type | Speed control | RPM sensing |
|---|---|---|
| 4-pin PWM | Full range | Yes (tachometer wire) |
| 3-pin DC (with tach) | None (runs at full speed) | Yes |
| 3-pin DC (no tach) | None (runs at full speed) | No |
| 2-pin | None (runs at full speed) | No |

3-pin fans are physically compatible with 4-pin headers (the PWM pin simply has no contact), but the controller cannot slow them down. All speed control, temperature curves, and RPM-PI modules require a 4-pin PWM fan.

The header itself carries 12V whenever the barrel jack is connected, regardless of the
speed setting. A fan set to 0%, or switched off in Home Assistant, still has 12V on its
supply pins. Unplug the barrel jack before swapping or rewiring a fan.

## PWM Spin-Down Behavior

The Intel 4-Wire PWM Fan Specification defines fan behavior at 100% duty cycle, but leaves the low end of the range to the fan manufacturer. Each fan has its own minimum duty cycle, stated in that fan's datasheet, and behavior below that minimum is undefined. A minimum somewhere around 20% is common in practice, but it is not a value the specification fixes.

Manufacturers implement that range differently: some fans have a hard minimum PWM threshold below which they stop responding and continue spinning at their minimum speed, while others can spin all the way down to 0 RPM at sufficiently low PWM values. Some fans in the latter group also exhibit hysteresis - they spin down to 0 RPM but will not restart until PWM rises above a higher threshold than the one that stopped them.

This matters for any control module that sweeps the full 0-100% output range. If a fan cannot spin down to 0 RPM, it will continue running at its minimum speed even when the controller output is 0%.

## Checking a Fan That Is Not Listed

The table below only covers fans someone has actually tested. For anything else, there are two ways to find out.

**Before you buy,** check the manufacturer datasheet for a stated speed at 0% PWM. Noctua publishes this under Performance Specifications as "Rotational speed @ 0% PWM". Most other manufacturers do not publish it at all, in which case the behavior is undetermined and you are buying on trust. Note that this is model-specific and not a property of the brand: the [NF-A20](https://www.noctua.at/en/products/nf-a20-pwm) in the table below does not stop, and the [NF-A6x25](https://www.noctua.at/en/products/nf-a6x25-pwm) specifies a 550 RPM minimum.

**If you already have the fan,** measure it instead of researching it. Plug it in, set that fan to 0% in Home Assistant, and watch its RPM sensor. A reading that settles at zero means the fan stops. A reading that settles at some non-zero value is the fan's minimum speed, and that is what the fan will do whenever the controller commands 0%. This takes under a minute and answers the question for the fan you actually own, which matters because most datasheets are silent on it.

## Community-Reported Fans

This table reflects user-reported observations. PWM behavior can vary between firmware revisions of the same fan model.

| Fan | Size | RPM Range (per spec) | Spins down to 0 RPM |
|-----|---|---|---|
| [Arctic P12 Max](https://www.arctic.de/en/P12-Max/ACFAN00280A) | 120 x 25 mm | 400-3300 RPM | Yes (user reported) |
| [Arctic S12038-4K](https://www.arctic.de/S12038-4K/ACFAN00296A) | 120 x 38 mm | 600-4000 RPM (400-4000 RPM tested) | No, holds 400 RPM when "off" (user reported, [#48](https://github.com/zeroflow/wifi-fancontroller/issues/48)); tested with 4 fans on rev 3.3, firmware 3.3 / ESPHome 2026.5.2 |
| [Arctic S4028-15k](https://www.arctic.de/S4028-15K/ACFAN00264A) | 40 x 28 mm | 1400-15000 RPM | No, holds 940-1900 RPM when "off" (user reported, [#54](https://github.com/zeroflow/wifi-fancontroller/issues/54)) |
| [be quiet! Pure Wings 3 120mm PWM high-speed](https://www.bequiet.com/de/casefans/4607) | 120 x 25 mm | 2100 RPM | No, holds 240-270 RPM when "off" (user reported, [#56](https://github.com/zeroflow/wifi-fancontroller/issues/56)) |
| Evercool EC7015H12EP | 70 x 15 mm | Not published | No, holds ~1500 RPM when "off", ~2600 RPM at full speed (user reported, [#70](https://github.com/zeroflow/wifi-fancontroller/issues/70)) |
| [Noctua NF-A14 Industrial PPC PWM 3000RPM](https://www.noctua.at/en/products/nf-a14-industrialppc-3000-pwm) | 140 x 25 mm | 0-3000 RPM | Yes (user reported) |
| [Noctua NF-A12x25 120mm PWM](https://www.noctua.at/en/products/nf-a12x25-pwm) | 120 x 25 mm | 0-2000 RPM | Yes (user reported) |
| [Noctua NF-A20 PWM](https://www.noctua.at/en/products/nf-a20-pwm) | 200 x 30 mm | 350-800 RPM | No (user reported) |
| [Thermaltake CT200](https://www.thermaltake.com/ct200-pc-cooling-fan-single-fan-pack.html) | 200 x 30 mm | 500-900 RPM | No (user reported) |

Almost every entry above is a 120 mm or larger PC case fan, because that is what most people have on hand to test. The two smaller formats reported so far, the 40 mm S4028 and the 70 mm Evercool, both hold a minimum speed rather than stopping. Two data points are not a rule, but small OEM-format fans rarely publish a 0% PWM figure either, so if you need a fan below 120 mm to stop completely, treat it as unverified until you have measured it yourself.

## What "Spins down to 0 RPM" Means in Practice

**Fans that do NOT spin down to 0 RPM:** When the controller output drops below the fan's minimum PWM threshold, the fan continues spinning at its minimum speed. The RPM sensor will still report a non-zero value and the fan will remain audible. For use cases where fans must fully stop (e.g., silence during idle), these fans are not suitable without additional hardware.

**Fans that DO spin down to 0 RPM:** The fan will stop when PWM drops low enough. If the fan also exhibits hysteresis, it may require a higher PWM value to restart than the value that stopped it. This can cause brief delays when the controller ramps up from 0%.

:::note[Hardware limitation]
If your use case requires fans to fully stop, choose a fan confirmed to spin down to 0 RPM. Switchable power outputs (cutting 12V to the fan header) are not currently supported by the controller hardware.
:::

## Adding Your Fan

This list is community-reported. If you have tested a fan not listed here, please [open a GitHub issue](https://github.com/zeroflow/wifi-fancontroller/issues) with the fan model, size, observed RPM range, and whether it spins down to 0 RPM.

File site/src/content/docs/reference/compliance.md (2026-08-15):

---
title: Safety and Compliance
description: Power supply requirements, RF exposure separation distance, and user button scope for the WiFi Fan Controller
---

This page carries the normative wording for the WiFi Fan Controller. Where any other page,
product listing, or printed insert says something different, the text on this page applies.

## Power supply

The Fancontroller requires an external 12 V DC SELV power supply, not included.

- **Connector:** 5.5 × 2.1 mm barrel jack, centre positive
- **Voltage:** 12 V DC ±5 %
- **Current:** minimum 2.5 A recommended, depending on fan load

The power supply is not part of the product. Users must supply a power source that is
certified for their region.

The 2.5 A figure is the maximum total input current of the board, set by the DC barrel jack.
It applies to the sum of all connected fans plus the board electronics, not per fan header.
Size the supply to the combined draw of the fans you connect, with headroom.

The USB-C port (Rev 2.0 and later) powers the microcontroller only. It cannot power fans.

The supply must be a regulated switch-mode (SMPS) 12 V DC unit. The input voltage must never exceed 15 V under any condition, including no load or light load.
The board itself draws under 50 mA, so an unregulated transformer-based supply, which has no
feedback regulation, can rise well above its rated voltage when lightly loaded.

**Warning:** do not use old transformer-based heavy brick adapters. These are often unregulated
and can output 15 to 18 V at light load, which permanently damages the board.

Damage caused by overvoltage from an unsuitable power supply is not a manufacturing defect and
is not covered under warranty.

How to identify an unsuitable supply:

- Heavy for its size
- Audible hum
- Ventilation slots on the casing
- Input marking that lists only "50 Hz" with no switching frequency listed
- Very old

If unsure, measure the output with no load connected. Do not use it if it reads above about 13 V.

Suitable supplies include modern regulated switching wall adapters, and MeanWell DIN-rail
supplies (for example the HDR or MDR series) for cabinet installations.

Tip: connect the barrel plug to the board first, then plug the adapter into mains.

## RF exposure

This product contains a radio transmitter. Install the product so that a separation distance
of at least 20 cm is maintained between the antenna and any person during normal operation.
This product is not intended to be worn on the body or operated in close proximity to the user.

## User buttons

The board provides three user-assignable push buttons connected to GPIO. They have no function
in the default configuration. Any behaviour is defined by the user's ESPHome configuration.
Typical use is setup, commissioning, or occasional manual override; regular operation is via
the network interface.

In the factory firmware the buttons are exposed to Home Assistant as binary sensors reporting
their pressed state. They trigger no action on the board itself unless you configure one.

See [USR Buttons](/reference/modules/usr-buttons/) for one ready-made way to assign them.

## Intended use

The WiFi Fan Controller is intended for the following operating conditions:

- Supply from an external 12 V DC SELV power supply, not included
- Operation in dry indoor locations only
- Connection of 4-pin PWM fans only
- Maximum total input current of 2.5 A

The 2.5 A figure is the maximum total input current of the board, set by the DC barrel jack.
It applies to the sum of all connected fans plus the board electronics. Size the supply to the
combined draw of the fans you connect, with headroom.

## Explicit exclusions

The WiFi Fan Controller is NOT suitable for, and must not be used in, the following
applications:

- Safety critical applications (for example personal protection, fire protection, emergency shutdown)
- Explosive atmospheres
- Medical applications
- Operation without an enclosure (open assembly with no protective cover)
- Unattended continuous operation without regular checks
- Use in motor vehicles or other vehicles

No suitability is warranted for any of these applications.

## External power supply requirements

The external power supply you provide must meet the following requirements:

- **Voltage:** 12 V DC
- **Regulation:** regulated switch-mode supply (SMPS), not an unregulated transformer-based supply
- **Maximum voltage:** must never exceed 15 V under any circumstances, including no load
- **Marking:** CE marked
- **Current limiting:** the supply must limit its output current
- **Polarity:** correct polarity, centre positive (5.5 × 2.1 mm barrel jack)

## Firmware notice

The Fancontroller ships with factory tested firmware. The declaration of conformity covers the
product in that state. Custom ESPHome YAML, custom modules or third party firmware may affect
CE conformity. Whether they do depends on what the change alters.

Configurations that stay within the documented envelope change neither the radio behaviour nor
the electrical behaviour the assessment rests on. These include a changed device name, changed
update intervals, an added temperature curve or a control module from this repository, and the
firmware update provided by the manufacturer.

CE conformity of the product as delivered is void, however, for changes that leave the
documented envelope. These include in particular:

- Altering radio parameters, for example transmit power via `wifi: output_power:`
- Changing the PWM output frequency away from 25 kHz
- Operating the outputs outside their specified limits
- Operation outside the intended use described in this document

Not every possible configuration can be assessed in advance. No general approval is therefore
given for modified firmware, and responsibility for a modified configuration rests with whoever
operates it.

Warranty claims are void for damage attributable to such a change.

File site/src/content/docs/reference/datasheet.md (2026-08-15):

---
title: Datasheet Rev 3.3
description: Product datasheet for the ESP32-S2 WiFi Fan Controller Rev 3.3, with electrical, mechanical, environmental and interface specifications
sidebar:
  label: Datasheet (Rev 3.3)
---

WiFi Fan Controller, hardware revision 3.3. A CE marked ESP32-S2 board that drives up to four
4-pin PWM fans, reads their tachometer signal, measures ambient temperature and humidity, and
integrates natively with Home Assistant through ESPHome.

Rev 3.1, 3.2 and 3.3 are electrically compatible and share this specification. Sub-revision
differences are manufacturing improvements only.

ESP32-S2 WiFi Fan Controller Rev 3.3 PCB front, showing the four PWM fan headers, the HDC1080 temperature and humidity sensor, the RGB status LEDs, the Qwiic port, the USB-C connector and the DC barrel jack

## Key features

- 4 independent 25 kHz PWM fan outputs with signal buffering
- 4 independent tachometer inputs, reported as RPM
- Onboard HDC1080 temperature and humidity sensor
- 5 addressable RGB status LEDs: one board status, one per fan connector
- WiFi 2.4 GHz, native Home Assistant integration via ESPHome
- Qwiic and 100 mil I2C expansion, NeoPixel output, SMD expansion header
- USB-C flashing, plus a UART0 serial header as fallback
- 3 user assignable push buttons

## Absolute limits and electrical specifications

| Parameter | Min | Typ | Max | Unit | Notes |
|---|---|---|---|---|---|
| DC input voltage | 11.4 | 12 | 12.6 | V | 12 V DC ±5 %, SELV, regulated SMPS only |
| DC input voltage, never to be exceeded | | | 15 | V | Including no load and light load |
| Total input current | | | 2.5 | A | Set by the DC barrel jack |
| Board electronics current, fans excluded | | 50 | | mA | |
| PWM output frequency | | 25 | | kHz | Per fan, independently controllable |
| PWM duty resolution | | | 100 | steps | ESPHome `speed_count: 100` |
| Logic level, all headers | | 3.3 | | V | Not 5 V tolerant |
| NeoPixel port voltage | | 5 | | V | |
| NeoPixel port current | | | 2 | A | |

The 2.5 A figure is the maximum total input current of the board. It applies to the sum of all
connected fans plus the board electronics. Size the supply to the combined draw of the fans you
connect, with headroom. See [Safety and Compliance](/reference/compliance/) for the normative
wording and for the full external power supply requirements.

The USB-C port powers the microcontroller only. It cannot power fans.

## Operating and storage conditions

| Parameter | Value | Reference |
|---|---|---|
| Climatic class | 3K3 | IEC 60721-3-3, weather protected indoor location |
| Ambient operating temperature | +5 to +40 °C | Bound of class 3K3 |
| Relative humidity | 5 to 85 %, non-condensing | Bound of class 3K3 |
| Pollution degree | 2 | IEC 62368-1 |
| Operating altitude | up to 2000 m | IEC 62368-1 |
| Ingress protection | none, bare PCB | An enclosure is required, see below |
| Installation | dry indoor locations only | |

Operation without an enclosure is an excluded application. The board is supplied as a bare
printed circuit assembly and must be installed inside a protective enclosure.

## Mechanical specifications

| Parameter | Value |
|---|---|
| PCB outline | 70.0 x 45.0 mm |
| PCB thickness | 1.6 mm |
| Mounting holes | 4x, 3.2 mm diameter |
| Mounting hole pattern | 60.0 x 35.0 mm rectangle, symmetric about the board centre |
| Mounting hole inset from edge | 5.0 mm on all four sides |
| Maximum component height above PCB | 11.0 mm |
| Maximum component height below PCB | 2.5 mm |
| Overall envelope | 70.0 x 45.0 x 15.1 mm |
| Weight | 17 g board, 56 g board with case |

A STEP model of the assembled board is available in the [`hardware/`](https://github.com/zeroflow/wifi-fancontroller/tree/main/hardware)
directory of the repository, for enclosure design and mounting clearance checks.

## Processing and wireless

| Parameter | Value |
|---|---|
| Module | ESP32-S2-MINI-2 |
| Core | Xtensa LX7, single core, up to 240 MHz |
| Flash | 4 MB |
| Antenna | integrated PCB antenna on the module |
| WiFi | 802.11 b/g/n, 2.4 GHz |
| Bluetooth | not available on ESP32-S2 |
| ESPHome board target | `esp32-s2-saola-1` |
| Framework | `arduino` |

The `arduino` framework is required: the NeoPixel output on GPIO42 uses the
`esp32_rmt_led_strip` platform, which does not work reliably with `esp-idf` on the ESP32-S2.

## Sensors and indicators

| Item | Specification |
|---|---|
| Temperature and humidity sensor | HDC1080, on the shared I2C bus |
| Default sensor update interval | 10 s |
| Tachometer input | pulse counter with internal pull-up, 2 pulses per revolution |
| Default RPM update interval | 1 s |
| Status LEDs | 5x SK6805 addressable RGB on GPIO1, WS2812 protocol, GRB order |
| LED assignment | LED 0 board status, LEDs 1 to 4 fan 1 to fan 4 |

## Connectors

| Connector | Type | Notes |
|---|---|---|
| DC input | barrel jack 5.5 x 2.1 mm, centre positive | 12 V DC, external supply not included |
| USB-C | USB 2.0 device | Flashing and logs, powers the MCU only |
| Fan 1 to 4 | 4-pin fan header, 2.54 mm pitch | Standard 4-wire PWM fans |
| I2C expansion | 5-pin, 100 mil pitch | GND, INT, SCL, SDA, +3V3 |
| Qwiic / STEMMA QT | JST-SH 4-pin, 1 mm pitch | Shares the I2C bus |
| NeoPixel | 3-pin | 5 V, 2 A maximum, GPIO42 |
| Serial | 4-pin | 3V3, TX, RX, GND, UART0 at 3.3 V logic |
| Expansion | SMD header, board bottom | GPIO2 to GPIO11 |

The Qwiic port, the 100 mil I2C port and the onboard HDC1080 are all on the same I2C bus
(GPIO33 SDA, GPIO34 SCL, 4.7 k pull-ups). Addresses must not conflict across those ports.

## Pin assignment

| Pin | Usage |
|---|---|
| GPIO0 | Boot button, push to enter flashing mode |
| GPIO1 | RGB status LEDs, SK6805, 5 LEDs |
| GPIO2 to GPIO11 | Expansion header, board bottom |
| GPIO12 | Fan 1 PWM |
| GPIO13 | Fan 2 PWM |
| GPIO14 | Fan 3 PWM |
| GPIO15 | Fan 4 PWM |
| GPIO16 | Fan 1 speed sense |
| GPIO17 | Fan 2 speed sense |
| GPIO18 | Fan 3 speed sense |
| GPIO21 | Fan 4 speed sense |
| GPIO26 | unused |
| GPIO33 | I2C SDA |
| GPIO34 | I2C SCL |
| GPIO35 | I2C INT |
| GPIO36 | USR3 button |
| GPIO37 | USR2 button |
| GPIO38 | USR1 button |
| GPIO42 | NeoPixel expansion port |
| GPIO43 | UART0 TX, serial header |
| GPIO44 | UART0 RX, serial header |
| GPIO45, GPIO46 | unused, strapping pins |

## Firmware and integration

| Item | Value |
|---|---|
| Firmware | ESPHome |
| Integration | Home Assistant, native API |
| Provisioning | Improv Serial, plus WiFi captive portal fallback |
| Updates | OTA via ESPHome, and HTTP update from the manifest below |
| Factory firmware | `fancontroller-r3-3-esp32s2.factory.bin` |
| Update manifest | `https://fancontroller.arthofer.dev/firmware/fancontroller-r3-3.manifest.json` |

Optional control modules for temperature curves, PID control, closed loop RPM regulation and
LED behaviour are documented under [Modules](/reference/modules/).

## Compliance

| Item | Status |
|---|---|
| CE marking | yes |
| RoHS | compliant |
| RF exposure | maintain at least 20 cm separation between the antenna and any person |
| Radio | contains a 2.4 GHz radio transmitter |

### Intended use

Supply from an external 12 V DC SELV power supply, operation in dry indoor locations only,
connection of 4-pin PWM fans only, maximum total input current 2.5 A.

### Excluded applications

The product is not suitable for and must not be used in safety critical applications,
explosive atmospheres, medical applications, operation without an enclosure, unattended
continuous operation without regular checks, or in vehicles.

### Firmware notice

The board ships with factory tested firmware, and the declaration of conformity covers the
product in that state. Custom ESPHome YAML, custom modules or third party firmware may affect
CE conformity, depending on what the change alters.

Configurations that stay within the documented envelope, such as a changed device name, an
added temperature curve or a control module from this repository, change neither the radio nor
the electrical behaviour the assessment rests on. Changes that leave it, in particular altering
radio parameters like transmit power, changing the PWM output frequency away from 25 kHz, or
operating the outputs outside their specified limits, void CE conformity of the product as
delivered. No general approval is given for modified firmware, and responsibility for a
modified configuration rests with whoever operates it.

Warranty claims are void for damage attributable to such a change.

The full normative wording is on the [Safety and Compliance](/reference/compliance/) page. Where
this datasheet and that page differ, that page applies.

## Ordering information

| Item | Value |
|---|---|
| Product | ESP32 WiFi Fan Controller |
| Hardware revision | 3.3 |
| Scope of delivery | assembled board with factory firmware |
| Not included | 12 V DC power supply, fans, enclosure |
| Shop | [Tindie](https://www.tindie.com/products/zeroflow/esp32-fancontroller/) |
| Documentation | [fancontroller.arthofer.dev](https://fancontroller.arthofer.dev) |
| Source and hardware files | [github.com/zeroflow/wifi-fancontroller](https://github.com/zeroflow/wifi-fancontroller) |

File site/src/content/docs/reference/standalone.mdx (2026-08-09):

---
title: Standalone Usage
description: Run the fan controller fully without Home Assistant, load modules from a local checkout, and group their entities in the web UI.
---

import { Steps, Aside } from '@astrojs/starlight/components';

The WiFi Fan Controller works completely on its own, without Home Assistant and without pulling optional modules from an external URL. This page covers three things: running the board standalone with its own web interface, loading modules from files already on your disk, and grouping module entities into named sections in that web interface.

## Standalone usage without Home Assistant

Home Assistant is optional, not required. When the board runs standalone, `api:` can be dropped from your configuration entirely, since there is no Home Assistant instance for it to authenticate against. Its replacement is ESPHome's built-in `web_server:` component at `version: 3`, served directly from the board at `http://<board-ip>`, with no cloud service and no companion app.

The web server is not enabled by default, and this page does not change that. It was removed from every configuration on 2026-03-06 in commit `895a55d`, in response to issue #21, for two reasons that are still valid: an unauthenticated HTTP server on port 80 with full fan control should not run on a customer's board unasked, and for Home Assistant users it is redundant attack surface with no benefit, since Home Assistant already talks to the board over the encrypted native API. Standalone use is the one case where that second reason does not apply: there is no Home Assistant taking over control, so enabling the web server here is not redundant, it is the control surface.

<Aside type="caution" title="Trusted network only">
The web server serves plain, unauthenticated HTTP by default.

- Trusted LAN only. Treat it like any other unauthenticated device on your network.
- Never expose it to the internet: no router port forwarding, no reverse proxy reachable from outside your LAN.
- If your network is shared with people or devices you do not fully trust, set an `auth:` block. See [Web Interface](/reference/web-server/) for the walkthrough.
</Aside>

`local: true` is mandatory for standalone use, not an optional tuning knob. Without it, the web interface fetches its JavaScript and CSS from esphome.io the first time a browser opens the page. That works fine when the board shares an internet-connected network, but a standalone board has no such guarantee, and the interface simply fails to load on a board with no internet access, which is exactly the case this page is about.

That convenience has a measured flash cost. Compiled against the finished [`examples/standalone.yaml`](https://github.com/zeroflow/wifi-fancontroller/blob/main/examples/standalone.yaml) on a Rev 3.1 board, the firmware uses 884,566 bytes (48.2%) without `web_server:`, and 992,826 bytes (54.1%) with `web_server: {version: 3, local: true}`, a delta of 108,260 bytes, about 5.9 percentage points of the app partition. That app partition is 1,835,008 bytes, one of the two OTA slots in the ESPHome default 4 MB flash layout that every configuration in this repository uses unmodified: nothing sets its own `partitions:` table. Rev 1.0 uses an ESP32 (`esp32dev`); Rev 2.0 through 3.3 use an ESP32-S2 (`esp32-s2-saola-1`).

WiFi provisioning does not need Home Assistant either:

<Steps>

1. **Fallback access point (`captive_portal:`).** If the board cannot join your WiFi network on first boot, or after a credential change, it opens its own access point named "Fancontroller Fallback." Connect to it from a phone or laptop, and a captive portal page lets you enter WiFi credentials.

2. **Browser-over-USB (`improv_serial:`).** Plug the board in over USB, and a compatible browser can provision WiFi credentials directly over the serial connection, using the Improv protocol.

</Steps>

Both components are already present in `examples/standalone.yaml`, and validate together with `web_server:` and no `api:` block.

MQTT is also a viable standalone control path if you already run a broker, though wiring it up is outside the scope of this page.

<Aside type="note" title="Keeping api: without Home Assistant">
ESPHome's `api:` component has a `reboot_timeout` that defaults to 15 minutes: if no client connects within that window, the board reboots. Nothing in this repository overrides it, so a board that keeps `api:` but never has Home Assistant connect will reboot every 15 minutes. Drop `api:` entirely if you do not need it, which is the recommended standalone approach, or set `reboot_timeout: 0s` if you want to keep `api:` around for another reason. This is cited from the ESPHome documentation, not verified against hardware in this phase.
</Aside>

A minimum standalone configuration needs no speed-control module at all. With nothing loaded beyond the hardware package and `web_server:`, the fans simply hold whatever speed they were last commanded to, and the web UI still exposes the four fan entities directly for manual control. [`examples/standalone.yaml`](https://github.com/zeroflow/wifi-fancontroller/blob/main/examples/standalone.yaml) goes one step further and loads a module: it is the complete, compiling starting point for the standalone and local-checkout workflows described on the rest of this page.

## Using modules from a local checkout

Pulling a module from GitHub is the default path, and it stays the recommended one for most readers. It is a convenience, not a requirement: every firmware config's `dashboard_import.package_import_url` points at a `github://` URL, so the standard adoption path genuinely does fetch from GitHub. But GitHub access is not required to use a module. If you would rather work from files already on your own disk, here are three ways to do that.

### Variant A: pull from GitHub (the default)

This is the shape already used throughout this repository, in every module's own usage header and in every example: a `packages:` entry with `url:`, `ref:`, and `files:`, optionally carrying `vars:`.

```yaml
packages:
  temperature_linear:
    url: https://github.com/zeroflow/wifi-fancontroller
    ref: main
    files:
      - path: modules/temperature_linear.yaml
        vars:
          friendly_name: "My Fan Controller"
          t_off: "25.0"
          t1: "30.0"
          t2: "50.0"
          fanpercent1: "30.0"
          fanpercent2: "100.0"
```

This is the most convenient path, and the right one for most readers: nothing to download, nothing to keep in sync yourself. `ref:` is what decides which version of the module you get; pin it to a tag or commit if you want a version that never changes underneath you, or leave it at `main` to always pull the latest.

### Variant B: download the files and use them locally

There are two ways to get the files onto your disk, depending on how much of the repository you want:

- **Clone the whole repository** with `git clone https://github.com/zeroflow/wifi-fancontroller`, which gives you `hardware-rev-3.1.yaml` and every file under `modules/` at once.
- **Download a single file**, if you only need one module: save `modules/temperature_linear.yaml` from GitHub's raw file view into your own project.

Either way, `packages:` changes from a remote URL to a local `!include`. The single most important detail here is the shape of that `!include`. The short scalar form passes no variables at all:

```yaml
# Passes NO vars: every substitution silently falls back to its module
# default. Fine only if every default is already what you want.
# The path is an example: point it at wherever the file sits on your system.
packages:
  temperature_linear: !include modules/temperature_linear.yaml
```

If you need to set even one variable, the mapping form with `file:` and `vars:` is the correct shape:

```yaml
# The paths are examples: point them at wherever the files sit on your system.
packages:
  hardware: !include hardware-rev-3.1.yaml
  temperature_linear: !include
    file: modules/temperature_linear.yaml
    vars:
      friendly_name: "My Fan Controller"
      t_off: "25.0"
      t1: "30.0"
      t2: "50.0"
      fanpercent1: "30.0"
      fanpercent2: "100.0"
```

Miss this and every substitution quietly takes its module-internal default. There is no error, just a config that behaves differently than the values you thought you set. If you land on "variable not defined," or a config that ignores values you typed into `vars:`, check whether the `!include` is the short scalar form or the mapping form first.

Get the relative path right for your own layout, not the repository's. `!include` resolves the path relative to the directory of the file doing the including, not the repository root and not your current working directory. A typical customer layout puts the config next to a `modules/` folder in the same directory:

```
my-fancontroller/
├── my-config.yaml
└── modules/
    └── temperature_linear.yaml
```

From `my-config.yaml`, that path is `modules/temperature_linear.yaml`, no `../` needed. The shipped `examples/standalone.yaml` looks different: it uses `../hardware-rev-3.1.yaml` and `../modules/temperature_linear.yaml`, because that file lives one directory below the repository root (`examples/`), while the hardware package and the `modules/` folder both sit at the root. Copy the example's `../` paths into a differently shaped directory and they will not resolve. Match the path to where your own files actually are.

Local use costs something in return: no automatic updates, `ref:` no longer applies since there is no remote source to pin a version of, and picking up a fix or a new feature means downloading the file again.

### Variant C: merge a module into your own config by hand

`modules/temperature_linear.yaml` is the smallest real speed-control module at 252 lines, and it is the same file variants A and B and `examples/standalone.yaml` already use, so one file carries you through the whole page. Merging it by hand means copying its blocks into the matching top-level key of your own config, and replacing every `${var}` placeholder with a fixed value:

- its `substitutions:` entries become literal values wherever `${t_off}`, `${t1}`, and so on appear, or you keep them as your own `substitutions:` if you want the placeholders to stay
- its `esphome: on_boot:` entry merges into your own `esphome:` block's `on_boot:` list
- its `number:`, `sensor:`, `output:`, and `switch:` lists merge into your own top-level `number:`, `sensor:`, `output:`, and `switch:` lists

For example, `${t_off}` in the module becomes a literal `25.0` directly in your `number:` entry once merged, instead of a substitution the module resolves for you:

```yaml
number:
  - platform: template
    name: Linear Off Temperature
    id: linear_t_off
    initial_value: 25.0 # was: ${t_off}
    min_value: 20
    max_value: 50
    step: 0.5
    unit_of_measurement: "°C"
    optimistic: true
```

This is worth doing when you intend to modify the module anyway, since you already have to edit the file to make the change. It gets painful fast on the larger modules: `modules/temperature_curve_triple_independent.yaml` is 1051 lines, and hand-merging that is a lot more to keep straight than swapping one `!include` line.

All three variants share two things worth knowing before you start.

Several speed-control modules cannot run at once: they all write to the same fan outputs, and having more than one active leads to unpredictable behavior. See the compatibility table on the [Modules Overview](/reference/modules/) page for the full list of which modules conflict.

A module also has to be loaded exactly once. Loading `modules/temperature_linear.yaml` both as a `github://` package and as a local `!include` in the same config collides: `esphome config` rejects it with a duplicate-entity error, confirmed by an actual run against this repository's files, because both copies declare the same component ids. Load a module one way or the other, never both.

## Grouping module entities in the web UI

The `web_server:` v3 UI can group entities into named, ordered sections instead of one flat list. Any entity carrying a `web_server:` sub-key (`sorting_group_id:` or `sorting_weight:`) requires the `web_server:` component to be declared in the same merged config, regardless of what the key's value is: an entity assigned to a group in a config with no `web_server:` block fails validation with "This option requires component web_server." If a module wrote that key into its own entity declarations, every Home Assistant user who loads that module without also declaring `web_server:`, which is the default, documented state for this board, would fail validation on their next update. That is why the assignment lives in your own config, the same place `examples/standalone.yaml` puts it, rather than inside the module file itself. It is exactly the kind of constraint that otherwise gets rediscovered the hard way, so it is written down here.

The shape, matching `examples/standalone.yaml`:

```yaml
web_server:
  version: 3
  local: true
  sorting_groups:
    - id: grp_temp_linear
      name: "Linear Temperature Control"
      sorting_weight: 100

number:
  - id: !extend linear_t_off
    web_server:
      sorting_group_id: grp_temp_linear
      sorting_weight: 10
```

`version: 3` is what adds grouping at all; the older default, `version: 2`, has no concept of `sorting_groups:`.

The [Modules Overview](/reference/modules/) page already notes that `!extend` is not for adding a new entity, only for changing one that already exists. That caution still holds here: what a grouping assignment does is add a new key to an entity the module already defines, which is exactly the case `!extend` is for, not the case the caution warns against.

Eleven modules get their own group this way. This table is the fixed set of group IDs and group-level weights that each module's own reference page uses in its copy-paste snippet:

| Group ID | Module | Weight | Band |
|---|---|---|---|
| `grp_temp_linear` | Temperature Linear | 100 | Speed Control |
| `grp_temp_curve` | Temperature Curve | 110 | Speed Control |
| `grp_temp_curve_dual` | Temperature Curve Dual | 120 | Speed Control |
| `grp_temp_curve_triple` | Temperature Curve Triple | 130 | Speed Control |
| `grp_temp_curve_triple_ind` | Temperature Curve Triple Independent | 140 | Speed Control |
| `grp_rpm_pi` | RPM PI Control | 150 | Speed Control |
| `grp_temp_pid` | Temperature PID | 160 | Speed Control |
| `grp_stall_guard` | Stall Guard | 200 | Safety |
| `grp_fallback_mode` | Fallback Mode | 210 | Safety |
| `grp_ds2484_onewire` | DS2484 1-Wire | 330 | Sensors |
| `grp_usr_buttons` | USR Buttons | 400 | Controls |

Every ID in this table is a fixed literal, copied verbatim from the module's own page. None of them is built from a substitution variable at config time. The [DS2484 1-Wire](/reference/qwiic/examples/ds2484/#web-ui-grouping) page explains why that module in particular cannot key its group off its display-name variable.

Inside a group, entities step by 10 in the order the module declares them (10, 20, 30, and so on). Diagnostic entities inside a group start at 900 and step by 10 from there, so diagnostics always sort last regardless of how many other entities the module adds later.

Three modules do not get a group this way, and it is worth saying so plainly rather than leaving the gap to be discovered: `bme680`, `bme680_bsec2`, and `scd41` declare their entities as nested sub-keys of one combined-sensor platform entry, for example `temperature:` and `humidity:` nested inside a single `platform: bme680` block, not as top-level list items with their own `id:`. `!extend` can only reach top-level ids, a limitation already documented on the [Modules Overview](/reference/modules/) page, so it cannot add a `web_server:` key to these nested entities. Those 14 entities fall back to ESPHome's own default grouping instead, by `entity_category`, which works and looks reasonable, but groups by category rather than by module. Each module's own reference page carries the exact copy-paste snippet for the modules this mechanism does reach.

## Related

- [Web Interface](/reference/web-server/) for the `auth:` walkthrough and the full `web_server:` options table
- [Modules Overview](/reference/modules/) for the module compatibility matrix and the `!extend` / `!remove` mechanics
- [`examples/standalone.yaml`](https://github.com/zeroflow/wifi-fancontroller/blob/main/examples/standalone.yaml) for the complete, compiling starting point
- [Troubleshooting](/getting-started/troubleshooting/) for other common issues

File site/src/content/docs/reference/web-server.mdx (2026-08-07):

---
title: Web Interface
description: Why the built-in ESPHome web server is disabled by default and how to enable it safely
---

import { Steps, Aside } from '@astrojs/starlight/components';

ESPHome can serve a small built-in web page directly from the board, letting you view and control entities from any browser at `http://<board-ip>`. On the WiFi Fan Controller this **web server is disabled by default**, so nothing listens on port 80 and a browser will report `ERR_CONNECTION_REFUSED`.

This page explains why it is off, and how to turn it on in your own ESPHome configuration.

## Why it is off by default

The firmware ships secure-by-default. The built-in web server is left out for two reasons:

- **Security.** Without authentication, the web interface is an open control surface: anyone on your network can reach `http://<board-ip>` and change fan speeds or read sensor data. Shipping it enabled by default would expose that surface on every board without the owner's consent.
- **Resources.** The web server component uses a significant amount of RAM and flash. Leaving it out keeps the default firmware lean, which matters on the ESP32-S2 used by Rev 2.0 and later.

You don't need the web server for normal use. Home Assistant talks to the board over the encrypted ESPHome native API, which is fully independent of port 80. All fan control, sensors, and automations work whether or not the web interface is enabled.

The one exception is running the board fully standalone, without Home Assistant at all. There, the web server is the control surface rather than a redundant one. See [Standalone Usage](/reference/standalone/) for that case.

<Aside type="note" title="dashboard_import does not enable it">
`dashboard_import` (with or without `import_full_config: true`) only tells the ESPHome Dashboard which package to base a new configuration on. It does not start a web server. To get the web interface back you have to add the `web_server` component to your configuration and re-flash or OTA the board, as shown below.
</Aside>

## Enabling the web interface

The web server is a standard [ESPHome component](https://esphome.io/components/web_server/). Add it to your own device configuration (the YAML you edit in the ESPHome Dashboard / add-on), then install the update over the air.

<Aside type="caution" title="Always set authentication">
Without an `auth:` block the interface is completely open to anyone on your network. Always configure a username and password.
</Aside>

<Steps>

1. **Add credentials to `secrets.yaml`**

   ```yaml
   web_server_username: "admin"
   web_server_password: "choose-a-strong-password"
   ```

2. **Add the `web_server` component to your device configuration**

   ```yaml
   web_server:
     port: 80
     auth:
       username: !secret web_server_username
       password: !secret web_server_password
   ```

3. **Install the update**

   Save and click **Install** in the ESPHome Dashboard to flash the board over the air. Once it reboots, open `http://<board-ip>` in a browser and log in with the credentials above.

</Steps>

## Configuration options

The most useful `web_server` options for this board. See the [ESPHome web_server documentation](https://esphome.io/components/web_server/) for the complete list.

| Option | Default | Description |
|---|---|---|
| `port` | `80` | TCP port the interface listens on. Use `80` for the standard `http://<board-ip>`. |
| `auth` | none | `username` / `password` block that gates access. Strongly recommended -- always set it. |
| `version` | `2` | Web UI version. `3` is the newest and adds entity grouping (`sorting_groups`); `2` is the well-tested default. |
| `include_internal` | `false` | When `true`, also shows entities marked `internal` (for example the per-fan RGB LEDs on Rev 3.x). |
| `local` | `false` | Serve the UI's JS/CSS from the board instead of a CDN, so it works without internet access. Uses more flash. |
| `ota` | (platform) | OTA over the web moved to its own `web_server` OTA platform. Set `ota: false` here to disable web OTA; the standard ESPHome Dashboard OTA is unaffected. |

<Aside type="tip" title="Memory">
The web server takes up a lot of RAM. If the board becomes unstable after enabling it, drop other optional components or use `version: 2` with `local: false` to keep the footprint small.
</Aside>

## Related

- [ESPHome web_server component](https://esphome.io/components/web_server/) -- full option reference
- [Home Assistant Integration](/getting-started/home-assistant/) -- the primary, encrypted control path (no web server needed)
- [Troubleshooting](/getting-started/troubleshooting/) -- other common issues

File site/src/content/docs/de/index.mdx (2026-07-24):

---
title: ESP32 WiFi Lüftersteuerung
description: CE-zertifizierte ESP32 Smart-Home-Lüftersteuerung für Home Assistant. Deutschsprachige Inhalte werden schrittweise ergänzt.
template: splash
hero:
  title: ESP32 WiFi Lüftersteuerung
  tagline: Diese deutsche Startseite ist ein Platzhalter. Die vollständige deutsche Übersetzung der Website folgt in einer späteren Phase.
  actions:
    - text: Zur englischen Website
      link: /
      variant: primary
---

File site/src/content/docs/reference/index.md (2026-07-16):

---
title: Reference
description: Technical reference for the WiFi Fan Controller
---

Detailed technical documentation for hardware revisions, firmware modules, and configuration options.

## Sections

### [Safety and Compliance](/reference/compliance/)

Power supply requirements, RF exposure separation distance, and the scope of the user buttons. This page carries the normative wording; where another page differs, this one applies.

### [Hardware Revisions](/reference/hardware/)

Pin assignments, board specifications, and revision comparison for every WiFi Fan Controller version from Rev 1.0 through Rev 3.3. Includes firmware installation instructions per board revision.

### [Modules](/reference/modules/)

Optional add-on packages for temperature control (PID, linear, curve), closed-loop RPM regulation, and RGB LED status indicators. Each module page documents configuration variables, Home Assistant entities, and usage examples.

### [Web Interface](/reference/web-server/)

Why the built-in ESPHome web server is disabled by default, and how to enable it safely with authentication in your own configuration.

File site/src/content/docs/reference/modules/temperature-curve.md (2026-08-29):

---
title: Temperature Curve
description: 5-point interpolated temperature curve module for custom fan profiles
sidebar:
  order: 3
---

:::note[All Revisions]
Works with all hardware revisions (Rev 1.0 through Rev 3.3).
:::

## Purpose

The Temperature Curve module lets you define a custom 5-point temperature-to-speed curve for granular control over fan behavior. Values between points are linearly interpolated, giving you a smooth speed transition across the entire temperature range.

## When to Use

Choose Curve when you need more control points than the linear module's three zones but don't need PID's automatic target-chasing behavior. It's ideal when you know exactly how you want fans to respond at specific temperatures.

For simpler threshold-based control, see [Temperature Linear](/reference/modules/temperature-linear/). For automatic temperature targeting, see [Temperature PID](/reference/modules/temperature-pid/). The [modules overview](/reference/modules/) has a comparison table.

:::tip[Works with Stall Guard]
This module cooperates with [Stall Guard](/reference/modules/stall-guard/) via a safety floor mechanism. If a fan stalls, Stall Guard sets a minimum speed that Temperature Curve will respect during recovery. No extra configuration needed, just include both modules.
:::

:::tip[Works with USR Buttons with Auto/Manual Mode]
A fan put into manual mode, from Home Assistant or from the board, is skipped by this module until it is released. No extra configuration is needed: the manual speed holds instead of being overwritten on the next ten-second tick. See [USR Buttons with Auto/Manual Mode](/reference/modules/usr-buttons-mode/).
:::

## Configuration

| Variable | Default | Description |
| --- | --- | --- |
| `friendly_name` | `"Fancontroller"` | Device name prefix for all entities |
| `curve_temp1` | `"20.0"` | Temperature point 1 (C) |
| `curve_speed1` | `"0.0"` | Fan speed at point 1 (%) |
| `curve_temp2` | `"25.0"` | Temperature point 2 (C) |
| `curve_speed2` | `"25.0"` | Fan speed at point 2 (%) |
| `curve_temp3` | `"30.0"` | Temperature point 3 (C) |
| `curve_speed3` | `"50.0"` | Fan speed at point 3 (%) |
| `curve_temp4` | `"40.0"` | Temperature point 4 (C) |
| `curve_speed4` | `"75.0"` | Fan speed at point 4 (%) |
| `curve_temp5` | `"50.0"` | Temperature point 5 (C) |
| `curve_speed5` | `"100.0"` | Fan speed at point 5 (%) |
| `temperature_sensor_id` | `"fancontroller_temperature"` | Id of the sensor supplying the control temperature |

## How It Works

The five temperature/speed pairs define a piecewise linear curve:

1. Each pair sets a "point" on the curve (e.g., 25 C = 25% speed)
2. Between any two adjacent points, the fan speed is linearly interpolated
3. Below the lowest temperature point, fans run at that point's speed
4. Above the highest temperature point, fans run at that point's speed

**Auto-sorting:** Temperature points are automatically sorted at runtime, so they work even if defined out of order. However, the module validates the curve at boot and logs a warning if points are not monotonically increasing.

A curve point of 0% drives the PWM output to 0%. Whether the fan then stops or holds a minimum speed is a property of the fan, not of the module. See [Fan Compatibility](/reference/fan-compatibility/) if you need the fans to come to a complete stop.

## Home Assistant Entities

### Number Entities

| Entity | Range | Step | Unit | Default | Description |
| --- | --- | ---- | ---- | --- | --- |
| Curve Temperature 1 | 0 -- 60  | 0.5  | C | 20.0 | Temperature point 1  |
| Curve Speed 1 | 0 -- 100 | 1 | % | 0 | Fan speed at point 1 |
| Curve Temperature 2 | 0 -- 60  | 0.5  | C | 25.0 | Temperature point 2  |
| Curve Speed 2 | 0 -- 100 | 1 | % | 25 | Fan speed at point 2 |
| Curve Temperature 3 | 0 -- 60  | 0.5  | C | 30.0 | Temperature point 3  |
| Curve Speed 3 | 0 -- 100 | 1 | % | 50 | Fan speed at point 3 |
| Curve Temperature 4 | 0 -- 60  | 0.5  | C | 40.0 | Temperature point 4  |
| Curve Speed 4 | 0 -- 100 | 1 | % | 75 | Fan speed at point 4 |
| Curve Temperature 5 | 0 -- 60  | 0.5  | C | 50.0 | Temperature point 5  |
| Curve Speed 5 | 0 -- 100 | 1 | % | 100 | Fan speed at point 5 |

### Sensor Entities

| Entity | Unit | Description |
| --- | ---- | --- |
| Curve Output | % | Current interpolated fan speed (updated every 10s) |

### Switch Entities

| Entity | Default | Description |
| --- | --- | --- |
| Auto Control Fan 1 | ON | Enable curve control for fan 1 |
| Auto Control Fan 2 | ON | Enable curve control for fan 2 |
| Auto Control Fan 3 | ON | Enable curve control for fan 3 |
| Auto Control Fan 4 | ON | Enable curve control for fan 4 |

### Binary Sensor

| Entity | Category | Description |
| --- | --- | --- |
| Curve Configuration Warning | Diagnostic | ON if temperature points are not monotonically increasing |

## Web UI grouping

This block goes in **your own configuration**, not in the module. See [why the assignment lives in the consuming config](/reference/standalone/#grouping-module-entities-in-the-web-ui) for the reason. `version: 3` is what makes entity grouping work at all; without it, entity grouping has no effect.

```yaml
web_server:
  version: 3
  sorting_groups:
    - id: grp_temp_curve
      name: "Temperature Curve"
      sorting_weight: 110

number:
  - id: !extend curve_temp1
    web_server:
      sorting_group_id: grp_temp_curve
      sorting_weight: 10
  - id: !extend curve_speed1
    web_server:
      sorting_group_id: grp_temp_curve
      sorting_weight: 20
  - id: !extend curve_temp2
    web_server:
      sorting_group_id: grp_temp_curve
      sorting_weight: 30
  - id: !extend curve_speed2
    web_server:
      sorting_group_id: grp_temp_curve
      sorting_weight: 40
  - id: !extend curve_temp3
    web_server:
      sorting_group_id: grp_temp_curve
      sorting_weight: 50
  - id: !extend curve_speed3
    web_server:
      sorting_group_id: grp_temp_curve
      sorting_weight: 60
  - id: !extend curve_temp4
    web_server:
      sorting_group_id: grp_temp_curve
      sorting_weight: 70
  - id: !extend curve_speed4
    web_server:
      sorting_group_id: grp_temp_curve
      sorting_weight: 80
  - id: !extend curve_temp5
    web_server:
      sorting_group_id: grp_temp_curve
      sorting_weight: 90
  - id: !extend curve_speed5
    web_server:
      sorting_group_id: grp_temp_curve
      sorting_weight: 100

sensor:
  - id: !extend curve_output_value
    web_server:
      sorting_group_id: grp_temp_curve
      sorting_weight: 110

switch:
  - id: !extend auto_control_fan1
    web_server:
      sorting_group_id: grp_temp_curve
      sorting_weight: 120
  - id: !extend auto_control_fan2
    web_server:
      sorting_group_id: grp_temp_curve
      sorting_weight: 130
  - id: !extend auto_control_fan3
    web_server:
      sorting_group_id: grp_temp_curve
      sorting_weight: 140
  - id: !extend auto_control_fan4
    web_server:
      sorting_group_id: grp_temp_curve
      sorting_weight: 150

binary_sensor:
  - id: !extend curve_config_warning_sensor
    web_server:
      sorting_group_id: grp_temp_curve
      sorting_weight: 900
```

## YAML Examples

### Basic Usage (Default Balanced Curve)

```yaml
packages:
  temperature_curve:
    url: https://github.com/zeroflow/wifi-fancontroller
    ref: main
    files:
      - path: modules/temperature_curve.yaml
        vars:
          friendly_name: "My Fan Controller"
```

### Silent Profile

Prioritizes low noise. Fans stay off until 25 C and ramp slowly, reaching only 80% at 55 C. Best for quiet home office environments where some temperature rise is acceptable.

```yaml
packages:
  temperature_curve:
    url: https://github.com/zeroflow/wifi-fancontroller
    ref: main
    files:
      - path: modules/temperature_curve.yaml
        vars:
          friendly_name: "Silent Cooler"
          curve_temp1: "20.0"
          curve_speed1: "0.0"
          curve_temp2: "25.0"
          curve_speed2: "20.0"
          curve_temp3: "35.0"
          curve_speed3: "40.0"
          curve_temp4: "45.0"
          curve_speed4: "60.0"
          curve_temp5: "55.0"
          curve_speed5: "80.0"
```

### Balanced Profile

Good all-around curve that balances noise and cooling. This is the default configuration.

```yaml
packages:
  temperature_curve:
    url: https://github.com/zeroflow/wifi-fancontroller
    ref: main
    files:
      - path: modules/temperature_curve.yaml
        vars:
          friendly_name: "Balanced Cooler"
          curve_temp1: "20.0"
          curve_speed1: "0.0"
          curve_temp2: "25.0"
          curve_speed2: "25.0"
          curve_temp3: "30.0"
          curve_speed3: "50.0"
          curve_temp4: "40.0"
          curve_speed4: "75.0"
          curve_temp5: "50.0"
          curve_speed5: "100.0"
```

### Aggressive Profile

Reacts quickly to temperature increases with steep ramp. Reaches full speed at 40 C. Best for high-performance setups where cooling takes priority over noise.

```yaml
packages:
  temperature_curve:
    url: https://github.com/zeroflow/wifi-fancontroller
    ref: main
    files:
      - path: modules/temperature_curve.yaml
        vars:
          friendly_name: "Aggressive Cooler"
          curve_temp1: "20.0"
          curve_speed1: "0.0"
          curve_temp2: "22.0"
          curve_speed2: "30.0"
          curve_temp3: "28.0"
          curve_speed3: "60.0"
          curve_temp4: "35.0"
          curve_speed4: "85.0"
          curve_temp5: "40.0"
          curve_speed5: "100.0"
```

### Server Profile

Always-on baseline cooling with rapid ramp. Fans never fully stop (20% minimum at 15 C), reaching full speed at just 35 C. Designed for server racks and network closets.

```yaml
packages:
  temperature_curve:
    url: https://github.com/zeroflow/wifi-fancontroller
    ref: main
    files:
      - path: modules/temperature_curve.yaml
        vars:
          friendly_name: "Server Rack"
          curve_temp1: "15.0"
          curve_speed1: "20.0"
          curve_temp2: "20.0"
          curve_speed2: "30.0"
          curve_temp3: "25.0"
          curve_speed3: "50.0"
          curve_temp4: "30.0"
          curve_speed4: "75.0"
          curve_temp5: "35.0"
          curve_speed5: "100.0"
```

## Tuning Tips

:::tip[Use the HA Number Entities]
All 10 curve parameters can be adjusted live from Home Assistant without reflashing. Experiment with different values and watch the Curve Output sensor to see the effect in real time.
:::

- **Watch the Configuration Warning sensor** -- if it shows ON in Home Assistant, your temperature points are not in ascending order. The module still works (points are auto-sorted at runtime), but it's best practice to define them in order for clarity.
- **Define temperatures in ascending order** -- while auto-sorting handles out-of-order points, having them in order makes your configuration easier to read and debug.
- **Start with the Balanced preset** -- the default curve works well for most scenarios. Adjust individual points based on your environment.
- **Consider your fans' minimum speed** -- if your fans need at least 20% PWM to spin reliably, make sure your lowest non-zero speed point is at or above that threshold.
- **Check whether your fans stop at 0%** - a 0% curve point does not guarantee a stopped fan. [Fan Compatibility](/reference/fan-compatibility/) lists tested fans and explains how to check yours.
- **Use the Curve Output sensor for debugging** -- it updates every 10 seconds and shows the current interpolated fan speed, making it easy to verify your curve behaves as expected at different temperatures.

## Controlling From a Different Sensor

By default the module reads `fancontroller_temperature`, the onboard HDC1080 that every hardware package declares. Set `temperature_sensor_id` to the id of any other temperature sensor in your configuration to control from that instead:

```yaml
packages:
  # modules/bme680.yaml is not standalone - it needs the shared I2C bus (bus_a)
  # that your hardware package declares. Use your own board revision here.
  hardware:
    url: https://github.com/zeroflow/wifi-fancontroller
    ref: main
    files: [hardware-rev-3.1.yaml]
  bme680:
    url: https://github.com/zeroflow/wifi-fancontroller
    ref: main
    files: [modules/bme680.yaml]
  temperature_curve:
    url: https://github.com/zeroflow/wifi-fancontroller
    ref: main
    files:
      - path: modules/temperature_curve.yaml
        vars:
          temperature_sensor_id: "bme680_temperature"
```

Omit the variable and it falls back to `fancontroller_temperature`, so existing configurations keep working unchanged. A misspelled id fails the build rather than quietly falling back to the onboard sensor.

The Qwiic modules build their sensor ids from an id-prefix substitution, so [BME680](/reference/qwiic/examples/bme680/) gives you `bme680_temperature`, [SCD41](/reference/qwiic/examples/scd41/) gives `scd41_temperature`, and [DS2484](/reference/qwiic/examples/ds2484/) gives whatever ids you assign your own `dallas_temp` sensors.

If you also run the [SSD1306 OLED](/reference/qwiic/examples/ssd1306/) module, note that it displays the onboard sensor regardless of this setting, so the screen and the fan control can show different temperatures.

The module names the sensor it is reading in its boot log, so you can confirm from a log dump that the override took effect.

:::caution[External sensors and startup]
A sensor that needs time before its first reading -- an SCD41 warming up, a BME680 on a long update interval, a Dallas probe -- reports no value for a while after boot. During that window this module commands the fans **off**. Keep the sensor's `update_interval` short if that matters to you, and expect the fans not to spin until the first reading lands. The onboard HDC1080 polls every 10 seconds and needs no warm-up, so the window is normally too short to notice; `modules/bme680.yaml` defaults to a 60 second interval, which stretches it considerably.
:::

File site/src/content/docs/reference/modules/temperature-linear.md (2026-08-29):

---
title: Temperature Linear
description: Simple linear temperature-to-fan-speed mapping module
sidebar:
  order: 2
---

:::note[All Revisions]
Works with all hardware revisions (Rev 1.0 through Rev 3.3).
:::

## Purpose

The Temperature Linear module provides a simple three-zone mapping from temperature to fan speed. Define your temperature thresholds and fan speed percentages, and the controller handles the rest -- no complex tuning required.

## When to Use

Choose Linear when you want straightforward temperature-based fan control without the complexity of PID tuning or multi-point curves. It works well for most home and office setups where you just need fans to ramp up as temperature rises.

For more precise temperature targeting, consider [Temperature PID](/reference/modules/temperature-pid/). For finer control over the speed curve shape, see [Temperature Curve](/reference/modules/temperature-curve/). The [modules overview](/reference/modules/) has a comparison table.

:::tip[Works with Stall Guard]
This module cooperates with [Stall Guard](/reference/modules/stall-guard/) via a safety floor mechanism. If a fan stalls, Stall Guard sets a minimum speed that Temperature Linear will respect during recovery. No extra configuration needed, just include both modules.
:::
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

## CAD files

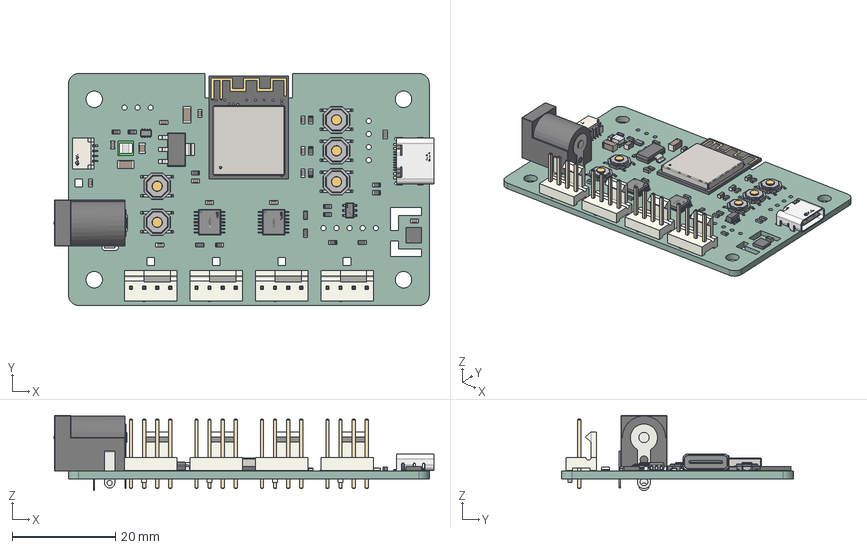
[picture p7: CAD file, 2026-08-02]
hardware/Wifi Fancontroller ESP32S2 Rev 3.3.step
73.7 x 45.0 x 14.6 mm
R_0603_1608Metric x 16
CONN-SMD_4P-P1.00_SM04B-SRSS-TB-LF-SN
LED-SMD_4P-L1.5-W1.5-BL x 5
C_0603_1608Metric x 12
SOT-583-8_L2.1-W1.2-P0.50-LS1.6-BL
TSSOP-14_L5.0-W4.4-P0.65-LS6.4-BL x 2
C_1206_3216Metric x 2
SW_SPST_TL3342 x 5
FanPinHeader_1x04_P2.54mm_Vertical x 4
BarrelJack_Horizontal
Texas_S-PWSON-N6
SOT-23-6_L2.9-W1.6-P0.95-LS2.8-BL
DFN1006.STEP^DFN1006.STEP_Submodel-SOD882_part_DesignRootModel_PCB_ES P32-S2-MINI-1_V1(2)_PCB_ESP32-S2-MINI-1_V1
C0201_20210301.STEP^C0201_20210301.STEP_Submodel-C0201_part_DesignRoo tModel_PCB_ESP32-S2-MINI-1_V1(2)_PCB_ESP32-S2-MINI-1_V1 x 15
trace_1^Submodel-MINI-ANT-TYPEC_3965454749_part_DesignRootModel_PCB_E SP32-S2-MINI-1_V1(2)_PCB_ESP32-S2-MINI-1_V1
R0201_20210301.STEP^R0201_20210301.STEP_Submodel-R0201_part_DesignRoo tModel_PCB_ESP32-S2-MINI-1_V1(2)_PCB_ESP32-S2-MINI-1_V1 x 3
XTAL3225_20210301.STEP^XTAL3225_20210301.STEP_Submodel-XTAL3225_part_ DesignRootModel_PCB_ESP32-S2-MINI-1_V1(2)_PCB_ESP32-S2-MINI-1_V1
ESP32-S2_20210301.STEP^ESP32-S2_20210301.STEP_Submodel-QFN56_0P4_7_pa rt_DesignRootModel_PCB_ESP32-S2-MINI-1_V1(2)_PCB_ESP32-S2-MINI-1_V1
L0201_20210301.STEP^L0201_20210301.STEP_Submodel-L0201_part_DesignRoo tModel_PCB_ESP32-S2-MINI-1_V1(2)_PCB_ESP32-S2-MINI-1_V1 x 2
C0402_20210301.STEP^C0402_20210301.STEP_Submodel-C0402_part_DesignRoo tModel_PCB_ESP32-S2-MINI-1_V1(2)_PCB_ESP32-S2-MINI-1_V1
uid__4^DesignRootModel_PCB_ESP32-S2-MINI-1_V1(2)_PCB_ESP32-S2-MINI-1_ V1
uid__4-0^DesignRootModel_PCB_ESP32-S2-MINI-1_V1(2)_PCB_ESP32-S2-MINI- 1_V1
uid__4-1^DesignRootModel_PCB_ESP32-S2-MINI-1_V1(2)_PCB_ESP32-S2-MINI- 1_V1
uid__4-2^DesignRootModel_PCB_ESP32-S2-MINI-1_V1(2)_PCB_ESP32-S2-MINI- 1_V1
uid__4-3^DesignRootModel_PCB_ESP32-S2-MINI-1_V1(2)_PCB_ESP32-S2-MINI- 1_V1
uid__4-4^DesignRootModel_PCB_ESP32-S2-MINI-1_V1(2)_PCB_ESP32-S2-MINI- 1_V1
uid__4-5^DesignRootModel_PCB_ESP32-S2-MINI-1_V1(2)_PCB_ESP32-S2-MINI- 1_V1
uid__4-6^DesignRootModel_PCB_ESP32-S2-MINI-1_V1(2)_PCB_ESP32-S2-MINI- 1_V1
uid__4-7^DesignRootModel_PCB_ESP32-S2-MINI-1_V1(2)_PCB_ESP32-S2-MINI- 1_V1
uid__4-8^DesignRootModel_PCB_ESP32-S2-MINI-1_V1(2)_PCB_ESP32-S2-MINI- 1_V1
uid__4-9^DesignRootModel_PCB_ESP32-S2-MINI-1_V1(2)_PCB_ESP32-S2-MINI- 1_V1
uid__4-10^DesignRootModel_PCB_ESP32-S2-MINI-1_V1(2)_PCB_ESP32-S2-MINI -1_V1
uid__4-11^DesignRootModel_PCB_ESP32-S2-MINI-1_V1(2)_PCB_ESP32-S2-MINI -1_V1
uid__4-12^DesignRootModel_PCB_ESP32-S2-MINI-1_V1(2)_PCB_ESP32-S2-MINI -1_V1
uid__4-13^DesignRootModel_PCB_ESP32-S2-MINI-1_V1(2)_PCB_ESP32-S2-MINI -1_V1
uid__4-14^DesignRootModel_PCB_ESP32-S2-MINI-1_V1(2)_PCB_ESP32-S2-MINI -1_V1
uid__4-15^DesignRootModel_PCB_ESP32-S2-MINI-1_V1(2)_PCB_ESP32-S2-MINI -1_V1
uid__4-16^DesignRootModel_PCB_ESP32-S2-MINI-1_V1(2)_PCB_ESP32-S2-MINI -1_V1
uid__4-17^DesignRootModel_PCB_ESP32-S2-MINI-1_V1(2)_PCB_ESP32-S2-MINI -1_V1
uid__4-18^DesignRootModel_PCB_ESP32-S2-MINI-1_V1(2)_PCB_ESP32-S2-MINI -1_V1
uid__4-19^DesignRootModel_PCB_ESP32-S2-MINI-1_V1(2)_PCB_ESP32-S2-MINI -1_V1
uid__4-20^DesignRootModel_PCB_ESP32-S2-MINI-1_V1(2)_PCB_ESP32-S2-MINI -1_V1
uid__4-21^DesignRootModel_PCB_ESP32-S2-MINI-1_V1(2)_PCB_ESP32-S2-MINI -1_V1
uid__4-22^DesignRootModel_PCB_ESP32-S2-MINI-1_V1(2)_PCB_ESP32-S2-MINI -1_V1
uid__4-23^DesignRootModel_PCB_ESP32-S2-MINI-1_V1(2)_PCB_ESP32-S2-MINI -1_V1
uid__4-24^DesignRootModel_PCB_ESP32-S2-MINI-1_V1(2)_PCB_ESP32-S2-MINI -1_V1
uid__4-25^DesignRootModel_PCB_ESP32-S2-MINI-1_V1(2)_PCB_ESP32-S2-MINI -1_V1
uid__4-26^DesignRootModel_PCB_ESP32-S2-MINI-1_V1(2)_PCB_ESP32-S2-MINI -1_V1
uid__4-27^DesignRootModel_PCB_ESP32-S2-MINI-1_V1(2)_PCB_ESP32-S2-MINI -1_V1
uid__4-28^DesignRootModel_PCB_ESP32-S2-MINI-1_V1(2)_PCB_ESP32-S2-MINI -1_V1
uid__4-29^DesignRootModel_PCB_ESP32-S2-MINI-1_V1(2)_PCB_ESP32-S2-MINI -1_V1
uid__4-30^DesignRootModel_PCB_ESP32-S2-MINI-1_V1(2)_PCB_ESP32-S2-MINI -1_V1
uid__4-31^DesignRootModel_PCB_ESP32-S2-MINI-1_V1(2)_PCB_ESP32-S2-MINI -1_V1
uid__4-32^DesignRootModel_PCB_ESP32-S2-MINI-1_V1(2)_PCB_ESP32-S2-MINI -1_V1
uid__4-33^DesignRootModel_PCB_ESP32-S2-MINI-1_V1(2)_PCB_ESP32-S2-MINI -1_V1
uid__4-34^DesignRootModel_PCB_ESP32-S2-MINI-1_V1(2)_PCB_ESP32-S2-MINI -1_V1
uid__4-35^DesignRootModel_PCB_ESP32-S2-MINI-1_V1(2)_PCB_ESP32-S2-MINI -1_V1
uid__4-36^DesignRootModel_PCB_ESP32-S2-MINI-1_V1(2)_PCB_ESP32-S2-MINI -1_V1
uid__4-37^DesignRootModel_PCB_ESP32-S2-MINI-1_V1(2)_PCB_ESP32-S2-MINI -1_V1
uid__4-38^DesignRootModel_PCB_ESP32-S2-MINI-1_V1(2)_PCB_ESP32-S2-MINI -1_V1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

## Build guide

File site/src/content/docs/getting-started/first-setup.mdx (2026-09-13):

---
title: First Setup
description: Connect your WiFi Fan Controller to WiFi, wire up your fans, and adopt it into Home Assistant
sidebar:
  order: 1
---

import FlashButton from '../../../components/FlashButton.astro';
import { Steps, Tabs, TabItem, Aside } from '@astrojs/starlight/components';

<Aside type="tip" title="Don't have a board yet?">
Get yours from the [Elecrow store](https://www.elecrow.com/wifi-fancontroller1.html).
</Aside>

Your board ships with factory firmware already flashed. This guide walks you from unboxing to a working fan controller in Home Assistant, covering WiFi provisioning, fan wiring, and Home Assistant adoption.

<Aside type="note" title="Already flashed from the factory">
Every WiFi Fan Controller is flashed with factory firmware before shipping. First-time users can skip straight to WiFi provisioning below. If you ever need to re-flash (corruption, recovery, or a custom ESPHome build), the "Re-flash firmware" section at the bottom of this page covers it.
</Aside>

## What You'll Need

- WiFi Fan Controller board
- USB-C data cable (not charge-only), used for serial-based WiFi provisioning
- An external 12V DC SELV power supply, not included. 5.5x2.1mm barrel jack, centre positive, 12V DC ±5%, minimum 2.5A recommended depending on fan load. See [Safety and Compliance](/reference/compliance/) for the full requirement.
- One or more PWM fans (4-pin). If your setup needs the fans to stop completely when idle, check [Fan Compatibility](/reference/fan-compatibility/) before buying. Many PWM fans hold a minimum speed instead of stopping at 0%.

<Aside type="caution" title="Use a regulated power supply">
The board requires a regulated switch-mode 12V DC supply. Do not use an old, unregulated
transformer-based "heavy brick" adapter. These can overvolt at light load and permanently
destroy the board. See [Safety and Compliance](/reference/compliance/) for the full power
supply requirement.
</Aside>

<Aside type="caution" title="RF exposure">
This product contains a radio transmitter. Install the product so that a separation distance of at least 20 cm is maintained between the antenna and any person during normal operation. This product is not intended to be worn on the body or operated in close proximity to the user.
</Aside>

## Setup Steps

<Steps>

1. **Connect to WiFi**

   Connect the board to your computer with a USB-C data cable.

   Open a tool that speaks Improv Serial (for example [improv-wifi.com/serial/](https://www.improv-wifi.com/serial/) in Chrome or Edge), or open a serial console connected to the board.

   Enter your **2.4 GHz** WiFi network name and password. 5 GHz networks are not supported by any board revision.

   Once connected, the board displays its IP address in the serial output.

   <Aside type="note" title="Fallback hotspot">
   If WiFi connection fails, the board creates a fallback hotspot called **"Fan Controller Fallback"**. Connect to this hotspot from your phone or laptop to reconfigure WiFi credentials.
   </Aside>

2. **Connect your fans**

   - Plug your **PWM fans** (4-pin) into the fan headers (Fan 1 through Fan 4)
   - Connect your **external 12V DC power supply** to the board's power input (5.5x2.1mm barrel jack, centre positive)
   - Check your hardware revision page for the correct pin layout and connector orientation
   - A fan that keeps spinning when you switch it off later is normal for some models, see [Fan Compatibility](/reference/fan-compatibility/)

   <Aside type="caution" title="USB-C does not power fans">
   The USB-C port is for flashing and serial communication only. Fans require 12V DC power through the barrel jack connector. The USB-C port provides only 5V to the ESP32 microcontroller.
   </Aside>

   <Aside type="tip" title="Connect and disconnect in this order">
   Connect in this order: the fans into the headers, then the barrel plug into the board,
   then the power supply into mains. Disconnect in the reverse order: mains first, then the
   barrel plug, then the fans.

   Plugging a fan into a rail that is already live draws a brief inrush spike that arcs
   across the mating contacts and pits them over many insertions. It also dips the 12V rail
   that all four headers share, which can glitch the fans that are already running. Avoiding
   it costs nothing.

   The barrel plug before mains step is also covered under
   [Safety and Compliance](/reference/compliance/).
   </Aside>

3. **Adopt in Home Assistant**

   Your fan controller is automatically discovered by Home Assistant via the ESPHome integration.

   - **If you have the ESPHome add-on:** The device appears in your ESPHome Dashboard. Click **Adopt** to add it.
   - **If you don't have the ESPHome add-on:** Go to **Settings > Devices & Services > Integrations**. The fan controller appears under **Discovered** devices. Click **Configure** to add it.

   Once adopted, your fan controller's entities (fans, temperature, humidity, RPM sensors) appear in Home Assistant ready to use.

   See [Home Assistant Integration](/getting-started/home-assistant/) for dashboard setup and automation examples.

</Steps>

## Re-flash firmware (optional)

You only need this section if:

- The factory firmware was corrupted (board will not boot or is not discovered on a fresh network)
- You want to reset to a known-good factory image
- You are installing a custom ESPHome build you compiled yourself

Most customers never need to re-flash. For routine firmware updates, use OTA through the [ESPHome Dashboard](/getting-started/firmware-updates/). No cables needed.

Re-flashing uses the Web Serial API and requires a Chrome or Edge browser plus a USB-C data cable.

<Tabs syncKey="revision">
  <TabItem label="Rev 3.3">
    <FlashButton manifest="/firmware/fancontroller-r3-3.manifest.json" label="Flash Rev 3.3" />

    See [Rev 3.x hardware details](/reference/hardware/rev-3-x/) for board specs and pin layout.
  </TabItem>
  <TabItem label="Rev 3.2">
    <FlashButton manifest="/firmware/fancontroller-r3-2.manifest.json" label="Flash Rev 3.2" />

    See [Rev 3.x hardware details](/reference/hardware/rev-3-x/) for board specs and pin layout.
  </TabItem>
  <TabItem label="Rev 3.1">
    <FlashButton manifest="/firmware/fancontroller-r3-1.manifest.json" label="Flash Rev 3.1" />

    See [Rev 3.x hardware details](/reference/hardware/rev-3-x/) for board specs and pin layout.
  </TabItem>
  <TabItem label="Rev 3.0">
    <FlashButton manifest="/firmware/fancontroller-r3-0.manifest.json" label="Flash Rev 3.0" />

    See [Rev 3.0 hardware details](/reference/hardware/rev-3-0/) for board specs and pin layout.
  </TabItem>
  <TabItem label="Rev 2.0">
    <FlashButton manifest="/firmware/fancontroller-r2-0.manifest.json" label="Flash Rev 2.0" />

    See [Rev 2.0 hardware details](/reference/hardware/rev-2-0/) for board specs and pin layout.
  </TabItem>
  <TabItem label="Rev 1.0">
    Rev 1.0 uses an ESP32 with a serial header instead of USB-C. You'll need a USB-to-serial adapter (3.3V FTDI or similar) connected to the programming header.

    <FlashButton manifest="/firmware/fancontroller-r1-0.manifest.json" label="Flash Rev 1.0" />

    See [Rev 1.0 hardware details](/reference/hardware/rev-1-0/) for board specs and pin layout.
  </TabItem>
</Tabs>

<Aside type="caution" title="USB not detected? (ESP32-S2)">
The ESP32-S2 (Rev 2.0+) has known USB reliability issues on some systems. Try these steps:

- Use a different USB-C cable (must be a **data** cable, not charge-only)
- Hold the **BOOT** button while plugging in the USB cable
- Try a different USB port (avoid USB hubs)
- Use [ESPWEBTOOL](https://esptool.spacehuhn.com/) as an alternative flash tool
</Aside>

After re-flashing, repeat the WiFi provisioning step above, then re-adopt in Home Assistant. See [Firmware Updates](/getting-started/firmware-updates/) for OTA updates.

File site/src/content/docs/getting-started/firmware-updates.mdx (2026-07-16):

---
title: Firmware Updates
description: Update your fan controller firmware over-the-air or via USB
sidebar:
  order: 3
---

import { Steps, Aside } from '@astrojs/starlight/components';

Your WiFi Fan Controller supports over-the-air (OTA) firmware updates through the ESPHome Dashboard in Home Assistant. USB reflashing is available as a fallback for recovery situations.

## OTA Updates (Recommended)

OTA is the easiest way to update your fan controller. No cables needed -- the update is pushed over your WiFi network.

<Steps>

1. **Open the ESPHome Dashboard** in Home Assistant (Settings > Add-ons > ESPHome)

2. **Check for updates** -- your fan controller shows an "Update Available" badge when new firmware is available

3. **Click Update** to start the OTA flash. The firmware is uploaded wirelessly to the board.

4. **Wait for reboot** -- the device reboots automatically with the new firmware (takes about 30 seconds)

5. **Verify** in Home Assistant that the device is online and all entities are working

</Steps>

<Aside type="note">
OTA updates require the device to be reachable on your network. If the device is unreachable or the update fails, use the USB reflashing method below.
</Aside>

## USB Reflashing (Fallback / Recovery)

Use USB reflashing when OTA is not possible -- for example if the device is unreachable, the firmware is corrupted, or the device won't boot.

<Steps>

1. **Disconnect the 12V power supply** from the board

2. **Connect the board via USB-C** to your computer

3. **Visit your hardware revision page** and use the flash button to reflash the factory firmware:
   - [Rev 3.x (3.1 / 3.2 / 3.3)](/reference/hardware/rev-3-x/)
   - [Rev 3.0](/reference/hardware/rev-3-0/)
   - [Rev 2.0](/reference/hardware/rev-2-0/)
   - [Rev 1.0](/reference/hardware/rev-1-0/)

4. **Re-provision WiFi** -- after flashing factory firmware, the board needs WiFi credentials again via Improv Serial or the fallback hotspot

5. **Re-adopt in Home Assistant** -- the device appears as a new device in the ESPHome Dashboard

</Steps>

<Aside type="caution" title="USB not detected? (ESP32-S2)">
The ESP32-S2 (Rev 2.0+) has known USB reliability issues on some systems. Try these steps:

- Use a different USB-C cable (must be a **data** cable, not charge-only)
- Hold the **BOOT** button while plugging in the USB cable
- Try a different USB port (avoid USB hubs)
- Use [ESPWEBTOOL](https://esptool.spacehuhn.com/) as an alternative flash tool
</Aside>

## Custom Firmware

If you've customized your ESPHome YAML configuration, you can compile and flash your own firmware builds.

**Via ESPHome Dashboard:**

1. Edit your device's YAML config in the ESPHome Dashboard
2. Click **Install** and choose **Wirelessly** (OTA) or **Plug into this computer** (USB)
3. ESPHome compiles and flashes the custom firmware automatically

**Via ESPHome CLI:**

```bash
# Compile your custom config
esphome compile my-fancontroller.yaml

# Flash over-the-air
esphome upload my-fancontroller.yaml

# Or flash via USB
esphome upload my-fancontroller.yaml --device /dev/ttyUSB0
```

Custom firmware retains OTA capability, so future updates can still be pushed wirelessly.

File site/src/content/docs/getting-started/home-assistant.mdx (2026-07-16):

---
title: Home Assistant Integration
description: Discover entities, build dashboards, and create automations with your fan controller
sidebar:
  label: Home Assistant
  order: 2
---

import { Aside } from '@astrojs/starlight/components';

Once your fan controller is [adopted in Home Assistant](/getting-started/first-setup/), its entities are available for dashboards and automations.

## Entities

After adoption, the following entities appear in Home Assistant:

| Entity | HA Domain | Description |
|---|---|---|
| Fan 1--4 | `fan` | PWM speed control (0--100%) |
| Temperature | `sensor` | Ambient temperature from HDC1080 sensor |
| Humidity | `sensor` | Ambient humidity from HDC1080 sensor |
| Fan 1--4 RPM | `sensor` | Tachometer readings (RPM) |
| Button USR1--3 | `binary_sensor` | Physical buttons on the board |

<Aside type="note" title="RGB LEDs (Rev 3.x only)">
Rev 3.x boards have 5 RGB LEDs (1 status + 4 per-fan) but they are marked as **internal** by default and won't appear in Home Assistant. To expose them, override `internal: false` on the light entities in your custom ESPHome config:

```yaml
light:
  - id: !extend status_led
    internal: false
  - id: !extend fan1_led
    internal: false
```
</Aside>

## Dashboard Setup

### Fan Control Card

Add a fan entity to your dashboard for direct speed control:

```yaml
type: entities
title: Fan Controller
entities:
  - entity: fan.fan_controller_fan_1
  - entity: fan.fan_controller_fan_2
  - entity: fan.fan_controller_fan_3
  - entity: fan.fan_controller_fan_4
```

### Temperature and Humidity

Use a sensor card or glance card to monitor the onboard HDC1080:

```yaml
type: glance
title: Environment
entities:
  - entity: sensor.fan_controller_temperature
  - entity: sensor.fan_controller_humidity
```

### RPM History Graph

Track fan speeds over time with a history graph card:

```yaml
type: history-graph
title: Fan RPM
hours_to_show: 24
entities:
  - entity: sensor.fan_controller_fan_1_speed
  - entity: sensor.fan_controller_fan_2_speed
  - entity: sensor.fan_controller_fan_3_speed
  - entity: sensor.fan_controller_fan_4_speed
```

## Automation Examples

### Temperature-Based Fan Speed

Increase fan speed when temperature rises above 30 C, reduce it when the temperature drops below 25 C:

```yaml
automation:
  - alias: "Increase fan speed when hot"
    trigger:
      - platform: numeric_state
        entity_id: sensor.fan_controller_temperature
        above: 30
    action:
      - service: fan.set_percentage
        target:
          entity_id: fan.fan_controller_fan_1
        data:
          percentage: 75

  - alias: "Reduce fan speed when cool"
    trigger:
      - platform: numeric_state
        entity_id: sensor.fan_controller_temperature
        below: 25
    action:
      - service: fan.set_percentage
        target:
          entity_id: fan.fan_controller_fan_1
        data:
          percentage: 30
```

### Night Mode Schedule

Lower fan speeds during nighttime hours to reduce noise:

```yaml
automation:
  - alias: "Night mode - quiet fans"
    trigger:
      - platform: time
        at: "22:00:00"
    action:
      - service: fan.set_percentage
        target:
          entity_id:
            - fan.fan_controller_fan_1
            - fan.fan_controller_fan_2
        data:
          percentage: 20

  - alias: "Day mode - normal fans"
    trigger:
      - platform: time
        at: "07:00:00"
    action:
      - service: fan.set_percentage
        target:
          entity_id:
            - fan.fan_controller_fan_1
            - fan.fan_controller_fan_2
        data:
          percentage: 50
```

### Fan Failure Alert

Get notified if a fan's RPM drops to zero while it should be running, which may indicate a failed or disconnected fan:

```yaml
automation:
  - alias: "Fan failure alert"
    trigger:
      - platform: numeric_state
        entity_id: sensor.fan_controller_fan_1_speed
        below: 1
        for:
          minutes: 2
    condition:
      - condition: state
        entity_id: fan.fan_controller_fan_1
        state: "on"
    action:
      - service: notify.persistent_notification
        data:
          title: "Fan Controller Alert"
          message: "Fan 1 RPM has dropped to zero. Check the fan connection."
```

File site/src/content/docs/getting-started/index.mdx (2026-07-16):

---
title: Getting Started
description: Get up and running with your WiFi Fan Controller
sidebar:
  label: Overview
  order: 0
---

import TrustStrip from '../../../components/TrustStrip.astro';

<TrustStrip />

Everything you need to go from unboxing to a fully operational fan controller in Home Assistant.

:::tip[Don't have a board yet?]
Pick one up from the [Elecrow store](https://www.elecrow.com/wifi-fancontroller1.html).
:::

## Guides

### [First Setup](/getting-started/first-setup/)

Connect your board to WiFi, wire up your fans, and adopt it into Home Assistant. Start here if you just received your board. Firmware comes pre-flashed from the factory.

### [Home Assistant Integration](/getting-started/home-assistant/)

Discover what entities your fan controller exposes, set up dashboard cards, and create automations for temperature-based fan control, scheduling, and failure alerts.

### [Firmware Updates](/getting-started/firmware-updates/)

Keep your fan controller up to date with over-the-air (OTA) updates through the ESPHome Dashboard, or reflash via USB if something goes wrong.

### [Troubleshooting](/getting-started/troubleshooting/)

Solutions to common issues including WiFi connectivity problems, fans not spinning, Home Assistant discovery failures, and USB detection issues.

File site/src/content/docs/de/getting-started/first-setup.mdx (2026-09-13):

---
title: Erste Einrichtung
description: Verbinden Sie Ihre WiFi Lüftersteuerung mit dem WLAN, verkabeln Sie Ihre Lüfter und binden Sie sie in Home Assistant ein
sidebar:
  order: 1
---

import FlashButton from '../../../../components/FlashButton.astro';
import { Steps, Tabs, TabItem, Aside } from '@astrojs/starlight/components';

<Aside type="tip" title="Noch keine Platine?">
Beziehen Sie Ihre Platine im [Elecrow-Shop](https://www.elecrow.com/wifi-fancontroller1.html).
</Aside>

Ihre Platine wird mit werkseitig geflashter Firmware ausgeliefert. Diese Anleitung führt Sie vom Auspacken bis zu einer funktionierenden Lüftersteuerung in Home Assistant, einschließlich WLAN-Einrichtung, Lüfterverkabelung und Home Assistant-Einbindung.

<Aside type="note" title="Werksseitig bereits geflasht">
Jede WiFi Lüftersteuerung wird vor dem Versand mit Werksfirmware geflasht. Nutzerinnen und Nutzer, die die Platine zum ersten Mal in Betrieb nehmen, können direkt zur WLAN-Einrichtung unten übergehen. Falls Sie jemals neu flashen müssen (Beschädigung, Wiederherstellung oder ein eigener ESPHome-Build), beschreibt der Abschnitt "Firmware neu flashen" am Ende dieser Seite das Vorgehen.
</Aside>

## Was Sie benötigen

- WiFi Lüftersteuerung Platine
- USB-C-Datenkabel (kein reines Ladekabel), für die serielle WLAN-Einrichtung
- Ein externes 12 V DC SELV-Netzteil, nicht im Lieferumfang enthalten. Hohlstecker 5,5 x 2,1 mm, Mittelpin positiv, 12 V DC ±5 %, mindestens 2,5 A empfohlen, abhängig von der Lüfterlast. Siehe [Sicherheit und Konformität](/de/reference/compliance/) für die vollständigen Anforderungen.
- Einen oder mehrere PWM-Lüfter (4-polig)

<Aside type="caution" title="HF-Exposition">
Dieses Produkt enthält einen Funksender. Installieren Sie das Produkt so, dass während des normalen Betriebs ein Mindestabstand von 20 cm zwischen der Antenne und Personen eingehalten wird. Dieses Produkt ist nicht dafür vorgesehen, am Körper getragen oder in unmittelbarer Nähe der Nutzerin oder des Nutzers betrieben zu werden.
</Aside>

## Einrichtungsschritte

<Steps>

1. **Mit dem WLAN verbinden**

   Verbinden Sie die Platine über ein USB-C-Datenkabel mit Ihrem Computer.

   Öffnen Sie ein Werkzeug, das Improv Serial unterstützt (zum Beispiel [improv-wifi.com/serial/](https://www.improv-wifi.com/serial/) in Chrome oder Edge), oder öffnen Sie eine serielle Konsole, die mit der Platine verbunden ist.

   Geben Sie den Namen und das Passwort Ihres **2,4 GHz**-WLAN-Netzwerks ein. 5 GHz-Netzwerke werden von keiner Platinenrevision unterstützt.

   Sobald die Verbindung hergestellt ist, zeigt die Platine ihre IP-Adresse in der seriellen Ausgabe an.

   <Aside type="note" title="Ausweich-Hotspot">
   Schlägt die WLAN-Verbindung fehl, richtet die Platine einen Ausweich-Hotspot mit dem Namen **"Fan Controller Fallback"** ein. Verbinden Sie sich von Ihrem Smartphone oder Laptop mit diesem Hotspot, um die WLAN-Zugangsdaten neu zu konfigurieren.
   </Aside>

2. **Lüfter anschließen**

   - Stecken Sie Ihre **PWM-Lüfter** (4-polig) in die Lüfteranschlüsse (Fan 1 bis Fan 4)
   - Verbinden Sie Ihr **externes 12 V DC-Netzteil** mit dem Stromeingang der Platine (Hohlstecker 5,5 x 2,1 mm, Mittelpin positiv)
   - Prüfen Sie die Seite Ihrer Hardware-Revision für die korrekte Pin-Belegung und Steckerausrichtung

   <Aside type="caution" title="USB-C versorgt keine Lüfter mit Strom">
   Der USB-C-Anschluss dient ausschließlich dem Flashen und der seriellen Kommunikation. Lüfter benötigen 12 V DC über den Hohlstecker-Anschluss. Der USB-C-Anschluss liefert nur 5 V an den ESP32-Mikrocontroller.
   </Aside>

   <Aside type="tip" title="Reihenfolge beim Anschließen und Trennen">
   Schließen Sie in dieser Reihenfolge an: zuerst die Lüfter an die Lüfteranschlüsse, dann
   den Hohlstecker an die Platine, dann das Netzteil an die Steckdose. Trennen Sie in
   umgekehrter Reihenfolge: zuerst die Steckdose, dann den Hohlstecker, dann die Lüfter.

   Wird ein Lüfter an eine bereits spannungsführende 12 V-Schiene gesteckt, entsteht ein
   kurzer Einschaltstromstoß, der an den Kontakten einen kleinen Lichtbogen erzeugt und sie
   über viele Steckzyklen hinweg abnutzt. Außerdem bricht die 12 V-Schiene kurz ein, die sich
   alle vier Anschlüsse teilen, was bereits laufende Lüfter stören kann. Es kostet nichts,
   das zu vermeiden.

   Den Teil "Hohlstecker vor Steckdose" finden Sie auch unter
   [Sicherheit und Konformität](/de/reference/compliance/).
   </Aside>

3. **In Home Assistant einbinden**

   Ihre Lüftersteuerung wird automatisch über die ESPHome-Integration von Home Assistant erkannt.

   - **Wenn Sie das ESPHome-Add-on haben:** Das Gerät erscheint in Ihrem ESPHome-Dashboard. Klicken Sie auf **Adopt**, um es hinzuzufügen.
   - **Wenn Sie das ESPHome-Add-on nicht haben:** Gehen Sie zu **Einstellungen > Geräte & Dienste > Integrationen**. Die Lüftersteuerung erscheint unter **Entdeckte** Geräte. Klicken Sie auf **Konfigurieren**, um sie hinzuzufügen.

   Nach der Einbindung erscheinen die Entitäten Ihrer Lüftersteuerung (Lüfter, Temperatur, Luftfeuchtigkeit, Drehzahlsensoren) einsatzbereit in Home Assistant.

   Siehe [Home Assistant Integration](/getting-started/home-assistant/) für Dashboard-Einrichtung und Automatisierungsbeispiele.

</Steps>

## Firmware neu flashen (optional)

Diesen Abschnitt benötigen Sie nur, wenn:

- die Werksfirmware beschädigt wurde (die Platine startet nicht oder wird in einem neuen Netzwerk nicht erkannt)
- Sie auf ein bekannt gutes Werksabbild zurücksetzen möchten
- Sie einen selbst kompilierten, eigenen ESPHome-Build installieren

Die meisten Kundinnen und Kunden müssen nie neu flashen. Für reguläre Firmware-Updates nutzen Sie OTA über das [ESPHome-Dashboard](/getting-started/firmware-updates/). Es sind keine Kabel nötig.

Das erneute Flashen nutzt die Web-Serial-API und erfordert einen Chrome- oder Edge-Browser sowie ein USB-C-Datenkabel.

<Tabs syncKey="revision">
  <TabItem label="Rev 3.3">
    <FlashButton manifest="/firmware/fancontroller-r3-3.manifest.json" label="Rev 3.3 flashen" />

    Siehe [Rev 3.x Hardware-Details](/de/reference/hardware/rev-3-x/) für Platinenspezifikationen und Pin-Belegung.
  </TabItem>
  <TabItem label="Rev 3.2">
    <FlashButton manifest="/firmware/fancontroller-r3-2.manifest.json" label="Rev 3.2 flashen" />

    Siehe [Rev 3.x Hardware-Details](/de/reference/hardware/rev-3-x/) für Platinenspezifikationen und Pin-Belegung.
  </TabItem>
  <TabItem label="Rev 3.1">
    <FlashButton manifest="/firmware/fancontroller-r3-1.manifest.json" label="Rev 3.1 flashen" />

    Siehe [Rev 3.x Hardware-Details](/de/reference/hardware/rev-3-x/) für Platinenspezifikationen und Pin-Belegung.
  </TabItem>
  <TabItem label="Rev 3.0">
    <FlashButton manifest="/firmware/fancontroller-r3-0.manifest.json" label="Rev 3.0 flashen" />

    Siehe [Rev 3.0 Hardware-Details](/de/reference/hardware/rev-3-0/) für Platinenspezifikationen und Pin-Belegung.
  </TabItem>
  <TabItem label="Rev 2.0">
    <FlashButton manifest="/firmware/fancontroller-r2-0.manifest.json" label="Rev 2.0 flashen" />

    Siehe [Rev 2.0 Hardware-Details](/de/reference/hardware/rev-2-0/) für Platinenspezifikationen und Pin-Belegung.
  </TabItem>
  <TabItem label="Rev 1.0">
    Rev 1.0 verwendet einen ESP32 mit einem seriellen Header anstelle von USB-C. Sie benötigen einen USB-zu-Seriell-Adapter (3,3 V FTDI oder ähnlich), der mit dem Programmier-Header verbunden wird.

    <FlashButton manifest="/firmware/fancontroller-r1-0.manifest.json" label="Rev 1.0 flashen" />

    Siehe [Rev 1.0 Hardware-Details](/de/reference/hardware/rev-1-0/) für Platinenspezifikationen und Pin-Belegung.
  </TabItem>
</Tabs>

<Aside type="caution" title="USB nicht erkannt? (ESP32-S2)">
Der ESP32-S2 (Rev 2.0+) hat auf manchen Systemen bekannte USB-Zuverlässigkeitsprobleme. Versuchen Sie Folgendes:

- Verwenden Sie ein anderes USB-C-Kabel (muss ein **Daten**kabel sein, kein reines Ladekabel)
- Halten Sie die **BOOT**-Taste gedrückt, während Sie das USB-Kabel einstecken
- Probieren Sie einen anderen USB-Port (vermeiden Sie USB-Hubs)
- Nutzen Sie [ESPWEBTOOL](https://esptool.spacehuhn.com/) als alternatives Flash-Werkzeug
</Aside>

Wiederholen Sie nach dem Neuflashen den WLAN-Einrichtungsschritt oben und binden Sie die Platine anschließend erneut in Home Assistant ein. Siehe [Firmware-Updates](/getting-started/firmware-updates/) für OTA-Updates.

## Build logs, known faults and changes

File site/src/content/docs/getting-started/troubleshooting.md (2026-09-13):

---
title: Troubleshooting
description: Solutions to common issues with the WiFi Fan Controller
sidebar:
  order: 4
---

Find solutions to common issues below. Each section is organized by symptom so you can jump directly to your problem.

## WiFi won't connect

- **Check your credentials** -- make sure you entered the correct WiFi network name and password during provisioning
- **2.4 GHz only** -- the ESP32 and ESP32-S2 do not support 5 GHz WiFi networks. This applies to all board revisions.
- **Check signal strength** -- move the board closer to your access point or check for interference
- **Fallback hotspot** -- if the board can't connect, it creates a hotspot called **"Fan Controller Fallback"**. Connect to this hotspot from your phone or laptop to re-enter WiFi credentials.
- **Factory reset** -- if nothing works, [reflash the factory firmware via USB](/getting-started/firmware-updates/) to start fresh

## Fans not spinning

- **Check 12V power** -- the fans are powered by the 12V DC barrel jack input, not USB-C. The USB-C port only provides 5V to the microcontroller and cannot power fans. Make sure your 12V power supply is connected and providing power.
- **Use PWM fans** -- the board controls fan speed via the PWM signal. Standard 3-pin DC fans won't respond to speed control (though they may run at full speed).
- **Check fan speed in HA** -- verify the fan speed is set above 0% in Home Assistant. A newly adopted device defaults to fans off.
- **Minimum startup speed** -- some fans require a higher PWM percentage to start spinning (typically 20-30%). Try setting the fan to 100% first, then lower gradually to find the minimum speed your fans support.
- **Check wiring** -- make sure the fan connector is fully seated and oriented correctly. See your [hardware revision page](/reference/hardware/) for pin diagrams.

## Fans keep spinning when set to off

- **This is usually the fan, not the board** - the Intel 4-wire PWM specification leaves behavior at very low duty cycles to the fan manufacturer. Many fans hold a minimum speed instead of stopping when the controller output reaches 0%.
- **Read the RPM sensor** - if a fan reports a steady non-zero RPM while its fan entity is switched off, that value is the fan's own minimum speed. [Fan Compatibility](/reference/fan-compatibility/) lists the fans that have been tested and explains how to check a fan that is not listed.
- **The board cannot switch 12V** - the fan headers are always powered while the barrel jack is connected. A fan that does not stop on its own cannot be stopped by the controller. Setting a fan to 0%, or switching its fan entity off in Home Assistant, does not de-energize the header, there is no software way to do it. To swap or rewire a fan, unplug the barrel jack first. If a hard stop is a firm requirement, pick a fan confirmed to spin down to 0 RPM.
- **3-pin fans always run at full speed** - a 3-pin DC fan has no PWM input and ignores the speed setting entirely. Check that your fan is a true 4-pin PWM model.

## Not showing in Home Assistant

- **ESPHome integration required** -- the fan controller uses the ESPHome native API. Make sure the [ESPHome integration](https://www.home-assistant.io/integrations/esphome/) is installed.
- **Same network/VLAN** -- the device must be on the same network as Home Assistant for mDNS discovery to work. If you use VLANs, ensure mDNS traffic can cross between them.
- **Manual add** -- go to **Settings > Devices & Services > Add Integration > ESPHome** and enter the device's IP address manually.
- **Check HA logs** -- look in **Settings > System > Logs** for API connection errors related to the fan controller.

## Web interface not reachable (port 80 refused)

- **The web server is off by default** -- the firmware ships without the built-in web interface for security and memory reasons, so `http://<board-ip>` returns `ERR_CONNECTION_REFUSED`. This is expected, not a fault.
- **Home Assistant does not need it** -- the board is controlled over the encrypted ESPHome API. Fan control, sensors, and automations all work without the web interface.
- **Enable it yourself** -- add the `web_server` component (with authentication) to your own ESPHome config and re-flash. See [Web Interface](/reference/web-server/) for the exact configuration, or [Standalone Usage](/reference/standalone/) if you're running without Home Assistant entirely.
- **`dashboard_import` won't do it** -- importing the package does not start a web server. You have to add the `web_server` block yourself.

## Temperature or humidity reads wrong

- **Sensor accuracy** -- the HDC1080 sensor has a typical accuracy of +/- 0.2 C for temperature and +/- 2% for relative humidity. Small deviations from a reference thermometer are expected.
- **Board self-heating** -- at high fan loads, components on the board generate heat that can affect the temperature reading. This is most noticeable in enclosed spaces with poor airflow around the board itself.
- **Stabilization time** -- allow 5 minutes after power-on for the sensor readings to stabilize.

## RPM shows 0 for a spinning fan

- **Tachometer wire required** -- the RPM sensor reads the fan's tachometer signal. Your fan must have a tach wire (3-pin fans with tach, or 4-pin PWM fans). 2-pin fans have no tachometer output.
- **Minimum speed threshold** -- some fans don't generate a reliable tach signal below a certain speed. Try increasing fan speed to 50% or higher to test.
- **Pulse counter configuration** -- if you're using a custom ESPHome config, verify the pulse counter sensor is configured for the correct GPIO pin matching your hardware revision.

## ESP32-S2 USB not detected

- **Try a different cable** -- many USB-C cables are charge-only and don't carry data. Use a cable that you know works for data transfer.
- **Hold BOOT button** -- hold the BOOT button on the board while plugging in the USB cable to force the board into bootloader mode.
- **Try a different USB port** -- some USB ports (especially through hubs) don't provide enough power or have compatibility issues. Use a port directly on your computer.
- **Use ESPWEBTOOL** -- try [ESPWEBTOOL](https://esptool.spacehuhn.com/) as an alternative flashing tool that may handle the USB connection differently.

## OTA update fails

- **Check network connectivity** -- make sure the device is reachable on your network. Try pinging its IP address.
- **Check flash space** -- very large custom configs may exceed available flash space. Check the ESPHome compile output for size warnings.
- **Retry once** -- transient network issues can interrupt OTA. Try the update again.
- **Fallback to USB** -- if OTA consistently fails, [reflash via USB](/getting-started/firmware-updates/) to restore a known-good firmware and try OTA again afterward.

---

## Still stuck?

Can't find a solution? [Open an issue on GitHub](https://github.com/zeroflow/wifi-fancontroller/issues) with details about your hardware revision, firmware version, and the problem you're experiencing.

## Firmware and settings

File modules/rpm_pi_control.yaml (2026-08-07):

# RPM PI Control Module
#
# PI (Proportional-Integral) controller that regulates PWM output to achieve target RPM.
# Each fan can have an independent target RPM, and the PI controller automatically
# adjusts the PWM duty cycle to maintain that speed.
#
# IMPORTANT: This module uses the existing fan speed sensors from the hardware package.
# Hardware Rev 3.1+ sensors update every 1s (fast enough for PI control).
# The default sensor configuration is sufficient for stable PI control.
#
# Usage:
#   packages:
#     hardware: !include hardware-rev-3.1.yaml
#     rpm_pi_control:
#       url: https://github.com/zeroflow/wifi-fancontroller
#       ref: main
#       files: 
#         - path: modules/rpm_pi_control.yaml]
#           vars:
#             friendly_name: "My Fan Controller"
#             kp: "50"              # Proportional gain (scaled by 100000, actual: 0.0005)
#             ki: "10"              # Integral gain (scaled by 100000, actual: 0.0001)
#             update_interval: "1s" # Control loop interval (matches 1s sensor update)
#
#   # OPTIONAL: Add filtering only if your fans have very noisy tachometer signals
#   sensor:
#     - id: !extend fan1_speed
#       filters:
#         - sliding_window_moving_average: {window_size: 3, send_every: 1}
#     # Repeat for fan2_speed, fan3_speed, fan4_speed...
# Local use (no github:// required): see /reference/standalone/
#
# Configuration Variables:
#   - friendly_name: Device name prefix (default: "Fancontroller")
#   - kp: Proportional gain coefficient scaled by 100000 (default: 50, actual: 0.0005)
#   - ki: Integral gain coefficient scaled by 100000 (default: 10, actual: 0.0001)
#   - update_interval: Control loop interval as an ESPHome time literal,
#                      e.g. "1s", "500ms" (default: "1s"). dt for the PI math
#                      is derived from real elapsed millis(), so the value here
#                      only sets how often the loop runs.
#
# Features:
#   - Individual target RPM setpoints for each of 4 fans
#   - Enable/disable PI control per fan with switches
#   - Live tuning of PI parameters via Home Assistant (scaled by 100000 for easy slider control)
#   - Real-time monitoring of error, P-term, I-term, and PWM output
#   - Anti-windup protection for integral term
#   - Deadband (dead zone) to prevent oscillation around setpoint
#   - I-term reset on large setpoint changes to prevent overshoot
#   - Smooth PWM output with clamping
#   - Uses existing hardware sensors (1s update rate is sufficient)
#
# Tuning Tips:
#   - Start with small kp (30-50) and ki (5-10) values (scaled by 100000)
#   - Increase kp first until you get quick response with slight overshoot
#   - Add ki to eliminate steady-state error
#   - Use deadband (5-20 RPM) to prevent oscillation around setpoint
#   - Set setpoint change threshold (200-500 RPM) to reset I-term on large changes
#   - Monitor the debug sensors to understand controller behavior
#   - If output oscillates, reduce kp/ki or increase deadband
#   - If response is too slow, increase kp

substitutions:
  friendly_name: "Fancontroller" # default
  kp: "50"      # Scaled by 100000, actual value: 0.0005
  ki: "10"      # Scaled by 100000, actual value: 0.0001
  update_interval: "1s"

# Globals for storing PI controller state
globals:
  # Integral terms for each fan (anti-windup protected)
  - id: fan1_integral
    type: float
    restore_value: no
    initial_value: '0.0'
  - id: fan2_integral
    type: float
    restore_value: no
    initial_value: '0.0'
  - id: fan3_integral
    type: float
    restore_value: no
    initial_value: '0.0'
  - id: fan4_integral
    type: float
    restore_value: no
    initial_value: '0.0'

  # Current PWM output values (0.0 - 1.0)
  - id: fan1_pwm_output
    type: float
    restore_value: yes
    initial_value: '0.0'
  - id: fan2_pwm_output
    type: float
    restore_value: yes
    initial_value: '0.0'
  - id: fan3_pwm_output
    type: float
    restore_value: yes
    initial_value: '0.0'
  - id: fan4_pwm_output
    type: float
    restore_value: yes
    initial_value: '0.0'

  # Previous target RPM values for detecting setpoint changes
  - id: fan1_prev_target
    type: float
    restore_value: no
    initial_value: '0.0'
  - id: fan2_prev_target
    type: float
    restore_value: no
    initial_value: '0.0'
  - id: fan3_prev_target
    type: float
    restore_value: no
    initial_value: '0.0'
  - id: fan4_prev_target
    type: float
    restore_value: no
    initial_value: '0.0'

  # Last control-loop run timestamp (millis) for dt calculation from real
  # elapsed time. Robust against scheduler jitter and WiFi-reconnect pauses.
  - id: pi_last_run_ms
    type: uint32_t
    restore_value: no
    initial_value: '0'
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

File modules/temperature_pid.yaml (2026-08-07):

# Temperature PID Control Module
#
# Advanced PID (Proportional-Integral-Derivative) temperature control for precise fan speed regulation.
# Automatically adjusts fan speeds to maintain a target temperature with minimal overshoot.
# Safety floor integration:
#   Respects fan{1-4}_safety_floor globals from the hardware package.
#   When a safety module (e.g. stall_guard) sets a floor, this module
#   will not command a running fan below that floor value.
#   Commanding a fan OFF (0%) is always honored - the floor only applies to non-zero speeds.
#   Safety floor takes precedence over both PID output and pwm_minimum_pid.
#
# Credit to https://github.com/patrickcollins12/esphome-fan-controller
#
# A PID simulator is available at https://fancontroller.arthofer.dev/pid-simulator.
# It uses simplified thermal models - treat results as a starting point for tuning.
#
# Usage:
#   packages:
#     temperature_pid:
#       url: https://github.com/zeroflow/wifi-fancontroller
#       ref: main
#       files:
#         - path: modules/temperature_pid.yaml
#           vars:
#             friendly_name: "My Fan Controller"
#             kp: "3.0"                          # Proportional gain (UI scale ×100: % fan per °C)
#             ki: "0.005"                        # Integral gain     (UI scale ×100)
#             kd: "0.0"                          # Derivative gain   (UI scale ×100)
#             max_integral: "0.0"                # Maximum integral term
#             output_averaging_samples: "1"      # Output smoothing samples
#             derivative_averaging_samples: "5"  # Derivative smoothing samples
# Local use (no github:// required): see /reference/standalone/
#
# Configuration Variables:
#   - friendly_name: Device name prefix (default: "Fancontroller")
#   - kp: Proportional gain coefficient (default: 0.03)
#   - ki: Integral gain coefficient (default: 0.00005)
#   - kd: Derivative gain coefficient (default: 0.0)
#   - max_integral: Max integral term value (default: 0.0)
#   - output_averaging_samples: Output averaging samples (default: 1)
#   - derivative_averaging_samples: Derivative averaging samples (default: 5)
#   - temperature_sensor_id: Id of the sensor supplying the control temperature
#       (default: fancontroller_temperature, the onboard sensor).
#   - min_temperature: Minimum Temperature shown for the climate component range
#   - max_temperature: Maximum Temperature shown for the climate component range
#   - target_temperature_step: Granularity allowed in the climate component  input
#   - current_temperature_step: Granularity shown in the climate component as current value
#
# Features:
#   - Climate entity (thermostat) for Home Assistant integration
#   - Live PID tuning via Home Assistant number entities
#   - Auto-tune button for automatic PID parameter calculation
#   - Deadband control to reduce oscillation near target temperature
#   - Manual override fan control
#   - Individual PID control switches for each of 4 fans
#   - Real-time monitoring of P, I, D terms and error values
#
# Tuning Tips:
#   - Use the "PID Climate Autotune" button for automatic tuning
#   - Start with low kp/ki/kd values and increase gradually
#   - Monitor the P/I/D term sensors to understand controller behavior
#
substitutions:
  friendly_name: "Fancontroller" # default
  # Sensor supplying the control temperature. Defaults to the onboard sensor
  temperature_sensor_id: fancontroller_temperature
  kp: "3.0"   # UI scale (×100): 3 ≈ 3% fan per °C
  ki: "0.005" # UI scale (×100)
  kd: "0.0"   # UI scale (×100)
  max_integral: "0.0"
  output_averaging_samples: "1"
  derivative_averaging_samples: "5"
  min_temperature: 20
  max_temperature: 50
  target_temperature_step: 0.1
  current_temperature_step: 0.1

# Validate configuration at boot
esphome:
  on_boot:
    - priority: -100 # Run late, after numbers are initialized
      then:
        - lambda: |-
            ESP_LOGI("temperature_pid", "Control sensor: ${temperature_sensor_id}");
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

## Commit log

2026-05-04 feat(quick-260422-tds): register USR Buttons in Starlight sidebar
    - Add USR Buttons entry after Stall Guard in Reference > Modules sidebar
    - English label: USR Buttons, German translation: USR-Tasten
    - Slug: reference/modules/usr-buttons
    - Sidebar now lists all seven modules in logical order
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2026-06-06 docs(quick-260606-u69-01): add 2.5A total input limit to hardware docs and first-setup
    - Add max total input current: 2.5A spec bullet to rev-1-0, rev-2-0, rev-3-0, rev-3-x
    - Clarify in all four pages that 2.5A is board-wide (DC barrel jack), not per fan header
    - Add PSU sizing note to first-setup.mdx "What You'll Need" power supply bullet
    - No em-dashes introduced; existing Aside components left untouched
    - Closes Issue #47 (maximum current per fan header not listed)
2026-06-13 docs(quick-260611-s2r): add Arctic S12038-4K to fan compatibility table
    Community-reported by prueckls: 4x Arctic S12038-4K running without
    issues on rev 3.3 (firmware 3.3 / ESPHome 2026.5.2). Spec range
    600-4000 RPM, tested 400-4000 RPM, holds 400 RPM when off (no spin-down
    to 0 RPM).
    closes #48
2026-06-18 docs(quick-260618-t2v): document TX/RX flashing header and Qwiic connector for Rev 3.x
    Add GPIO43 (UART0 TX/U0TXD) and GPIO44 (UART0 RX/U0RXD) to the pin table
    (previously skipped), a Serial Flashing Header (TX/RX) section, and a Qwiic
    Connector section noting the shared I2C bus with the 100mil port and HDC1080.
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2026-07-16 docs(qwiic): source the power budget to SparkFun, make pull-ups testable
    Retitle "The 3.3V budget" as "The Qwiic cable sets the power budget":
    the binding limit is SparkFun's conservative 226mA Qwiic cable rating,
    not the board's 3.3V rail, which has headroom to spare. Against the
    SCD41's ~17mA (heaviest module), that is roughly 13 modules, so power
    is not the constraint anyone actually hits.
    Rework the pull-up section to give two customer-runnable methods
    (ohmmeter, oscilloscope) plus an ESPHome-log pass/fail fallback,
    instead of an unmeasured module-count open point. The 10k/2k2 worked
    example is kept as an illustration of why the answer depends on the
    customer's breakouts, not a guarante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
2026-07-16 docs(qwiic): lead pull-up section with SparkFun's disable rule of thumb
    - Replace unsourced hedge with sourced facts: SparkFun Qwiic boards fit
    2.2k with a cuttable jumper, Adafruit STEMMA QT spec only expects
    pull-ups without specifying a value
    - Lead with SparkFun's rule of thumb (disable all but one pair) as the
    actionable answer, since the board already fits the one pair needed
    - Reframe the ohmmeter/oscilloscope/log tests as verification rather
    than the primary answer
    - Correct the worked illustration: 10k is specific to one Adafruit
    breakout (#5961), not a general Adafruit value
2026-07-16 docs(qwiic): correct Qwiic attribution, SparkFun made the standard not the connector
    The connector is JST's SH series (SM04B-SRSS-TB on this board); SparkFun
    created the Qwiic system around it.
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2026-07-16 docs(compliance): frame the USR buttons as assignable, not as the control surface
    The module page sold the buttons as an ongoing physical UI ('without
    touching Home Assistant', 'when reaching for a phone or computer is
    inconvenient'), which collides with the 20 cm separation the module
    certificate's RF exposure adoption depends on. The feature and the page
    stay; the framing moves from how you operate the device to how you can
    assign the buttons, with regular operation over the network interface.
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2026-07-17 docs(qwiic): add a bench-tested five-module medley to the combining page
    The page explained the four rules of a shared bus one at a time but never
    showed them colliding in a single config. This adds one that runs the
    OLED, BME680, SCD41, and DS2484 with two DS18B20 probes together, and a
    table mapping each rule to how that config resolves it.
    The display lambda replaces the OLED module's fan-RPM screen via
    !extend on its top-level id and puts all five temperatures on screen as
    a 3x2 grid. Cell positions come from i % 3 and i / 3 rather than twelve
    hardcoded coordinates, so a sixth reading is an array change. The last
    cell shows the spread between the warmest and coldest sensor, which
    tracks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
2026-07-19 docs(modules): add Temperature Curve Triple reference page
    - New reference page for the three-profile shared-axis module
    - Bump sidebar order on the four pages that follow so the new
    page at order 5 does not collide with RPM PI Control
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2026-07-19 fix(modules): validate the live temperature axis, not just boot defaults
    The failsafe gate was set at boot from the substitution defaults, while
    the runtime lambda interpolates the live number states. Those diverge:
    the axis numbers are restore_value: true and editable from Home
    Assistant, so after the first boot the validated values may not be the
    values in use.
    Since this module deliberately does not sort, editing the axis into a
    non-ascending order in Home Assistant silently produced meaningless
    interpolation with no warning and no failsafe. The dual module was not
    exposed to this because it sorts at runtime.
    Re-check the live axis on every sensor update and trip the same 100%
    failsafe,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
    [temperature_curve_triple.yaml]
2026-07-19 refactor(modules): drop the redundant boot-time axis check
    The axis numbers use initial_value: ${axis_temp*}, so on first boot the
    live states equal the substitution defaults. The live check added in the
    previous commit therefore catches everything the boot check caught, just
    up to one update cycle later. Keeping both meant two validation paths
    for one invariant, which is exactly the kind of duplication that drifts.
    Remove the boot axis check and the curve_config_valid global. One axis
    check remains, against the live states.
    The profile speed check stays at boot: it is informational, never gates
    operation, and is a hint about intent rather than a correctness guard.
    Verified by compiling t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
    [temperature_curve_triple.yaml]
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2026-07-19 ci(deps): report when the pinned ESPHome version falls behind upstream
    - read esphome-version from publish-firmware.yml instead of duplicating it
    - query the latest non-prerelease release of esphome/esphome
    - update an existing labelled issue in place rather than filing a new one weekly
    - report only, the pin is never bumped automatically
    Dependabot already covers the action pins, but not this input value.
2026-07-19 fix(ci): stop redirecting the selector stdout into GITHUB_OUTPUT
    The affected-examples selector both redirected its stdout into
    GITHUB_OUTPUT and opened that file to write its outputs directly. The
    diagnostic lines it prints for the log therefore landed in the output
    file too, where "=== Changed files ===" is not a valid name=value pair,
    so the runner failed the step with "Value cannot be null". It also meant
    the selection summary never appeared in the log, which is the one place
    it needs to be visible so that a narrow selection is never mistaken for
    full coverage.
    Drop the redirect and keep the direct write.
2026-07-19 feat(test): pin the ESPHome image tag through ESPHOME_VERSION
    The wrapper ran the untagged image, so a run used whatever "latest" was
    cached locally and never said which version that was. On this machine
    that resolved to 2026.2.4 while upstream latest was 2026.7.0, so a green
    sweep looked like it covered the current release when it did not.
    Default stays "latest" so existing use is unchanged. The resolved image
    is echoed to stderr, keeping it out of config dumps that get piped.
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2026-07-19 fix(test): default the example sweep to the shipped ESPHome pin
    test-examples.sh called esphome.sh without setting a version, so it
    inherited the "latest" default, which is whatever the local docker cache
    happens to hold. A sweep therefore tested an unknown version and said so
    nowhere.
    This is the same defect 793b218 fixed one level down in esphome.sh. That
    commit pinned the image tag but nothing passed a tag in, so the harness
    above it kept the ambiguity. The consequence showed up while closing out
    260719-tma: --compile with-usr-buttons-rev-3.1 exited 1 on a CMake error
    resolving esp_hal_ieee802154, which looked like a broken example. It was
    a stale cached 2026.2.4. The same command on the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
2026-07-20 feat(19-01): default esphome.sh to the release pin and add container passthrough
    - Replace the ESPHOME_VERSION:-latest default with the pin-resolution block
    ported from test-examples.sh, reading .github/workflows/publish-firmware.yml
    with the same strict version-shape guard and loud abort (D-14)
    - Resolve PIN_FILE relative to the script's own location via BASH_SOURCE so
    the pin still resolves when called from another working directory, without
    cd-ing (which would change what gets bind-mounted as /config)
    - Add an in-container passthrough: when the esphome CLI is already on PATH,
    exec it directly instead of starting a nested docker run, so the same
    wrapper works inside a CI contai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
2026-07-20 feat(19-01): widen test-examples.sh to sweep the 12 board configs too
    - Add ALL_PATHS collection covering fancontroller-rev*.yaml (all 12 board
    configs, plain and .factory.yaml, via the unmodified glob) ahead of the
    existing .test-build/*.yaml example sweep, so the two cold per-chip-family
    builds happen first and the example sweep runs warm (D-13)
    - Pass full relative paths through to ./esphome.sh config/compile instead of
    hardcoding the .test-build/ prefix and .yaml suffix, since the two sources
    now live at different paths
    - SELECT still matches on the basename with .yaml stripped, so existing
    single-config invocations keep working unchanged
    - Config-fail gate and phase semantic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
2026-07-20 fix(19-01): delete compile.sh, broken subset of esphome.sh
    compile.sh carries no image tag so it resolves to whatever "latest" happens
    to be cached, forces -it so it fails with an input-device error under any
    non-interactive caller, and passes its argument unquoted so paths with
    spaces break. esphome.sh is the corrected superset (D-10). The only surviving
    reference is CLAUDE.md line 18, which plan 03 removes alongside the other
    documentation updates for this phase.
2026-07-20 feat(19-02): create validate.yml with trigger, release-version, config jobs
    - Fail-safe paths-ignore trigger replaces the ci.yml allowlist that missed
    publish-firmware.yml and esphome.sh (D-07)
    - release-version job duplicated in full from ci.yml, intentional per D-06
    - config job runs inside the pinned ghcr.io/esphome/esphome container with
    no interpreter setup or pip install step (D-04/D-05), still covers all
    17 examples plus all 12 board configs including .factory.yaml variants
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2026-07-20 feat(19-02): wire actionlint as a lint-workflows job
    - lint-workflows runs on ubuntu-latest with no needs:, checks out the
    repo, and lints the whole .github/workflows/ directory via
    rhysd/actionlint:1.7.12 through docker run, the same invocation a
    developer runs locally, rather than a marketplace action
    - pinned to the resolved current release tag (1.7.12), not a floating one
    - verified clean: running the pinned image against .github/workflows/
    reports no findings across all five workflow files present
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2026-07-20 fix(19-02): pin bash for validate.yml's two array-using container steps
    The first real run of validate.yml failed at the config sweep with
    "Syntax error: \"(\" unexpected" (exit 2). GitHub Actions defaults a
    container job's run steps to sh, which in this image is dash, and both
    sweep steps use bash arrays (FAILED=(), FAILED+=(), ${#FAILED[@]}).
    - Declare shell: bash on "Validate every config" and "Compile affected
    examples" rather than relying on the runner's default shell probe.
    The image ships bash at /usr/bin/bash, verified against the pinned tag.
    - Reproduced the failure verbatim under dash and confirmed the same
    script runs correctly under bash, both inside 2026.7.0.
    - compile-ma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
2026-07-24 feat(19.1-01): register de Starlight locale, add minimal DE splash page
    - astro.config.mjs: add locales block (root=en, de=de) per D-03
    - src/content/docs/de/index.mdx: minimal DE homepage so /de/ resolves
    and carries og:image, restoring the verify-seo.sh DE_HOME og:image
    check without translating the full homepage (out of scope, D-03)
2026-07-24 feat(19.1-01): create verify-manual.sh Wave 0 PASS/FAIL harness
    - Modeled on site/scripts/verify-seo.sh's PASS/FAIL counter idiom
    - Flags: --sections --lang --r4 --r5 --r6 --r7 --r9 --footer --umlaut
    (no flag = run all); reads site/dist/de/manual-print/index.html for
    grep-able checks (R1/R2/R4/R5/R6/R7/R9) and site/manual.pdf via
    pdftotext for PDF-only checks (--footer/R3, --umlaut)
    - R4/P2 and R7/P1 negative checks are deliberate blanket phrase
    matches with no allowlist/exception per the plan's explicit
    instruction, so plan 02's legal text must avoid the forbidden
    per-port and full-liability-exclusion phrasing entirely, not just
    negate it
    - PDF-only flags skip gracefully (not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
2026-07-24 feat(19.1-02): create DE translations of first-setup and hardware rev pages
    - German translation of first-setup.mdx (WLAN/wiring/Home Assistant flow)
    - German translations of rev-1-0/2-0/3-0/3-x.mdx hardware pages, preserving
    pin tables, image paths, and manifest URLs unchanged (language-neutral)
    - New de/reference/hardware/index.md landing page so the DE hardware
    section resolves
    - Every page carries the review-pending marker; the 2.5 A inclusive-total
    wording is preserved across all four hardware revs without per-port phrasing
2026-07-24 feat(19.1-03): create concatenated DE manual-print route with fixed TOC
    - src/pages/de/manual-print/index.astro: standalone (no Starlight chrome)
    route, hard-coded sectionIds array is the fixed R1/D-10 TOC (compliance,
    first-setup, 4 hardware revs), getEntry() throws loudly on any missing
    DE entry (R2), scoped @media print CSS
    - Fix (Rule 1): verify-manual.sh's excluded-surface check swapped a blanket
    "Qwiic" marker for "STEMMA QT" - the curated hardware pages legitimately
    mention the board's own Qwiic connector, which is different content from
    the excluded reference/qwiic/* examples section
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2026-08-05 revert: leave temperature_curve_triple to the per-profile work on main
    main already gives triple a source sensor per profile, curve_a_sensor_id,
    curve_b_sensor_id and curve_c_sensor_id, together with a NAN hold and
    failsafe, and temperature_curve_triple_independent uses the same scheme.
    Those commits are not pushed yet, which is why GitHub still reports this
    PR as mergeable when the merge would in fact conflict on this file.
    Restore both triple files to the merge base so this PR touches no part of
    that work. The single temperature_sensor_id stays in curve, dual, linear
    and pid, where it is the whole point of the change. Unifying the name
    across the module family, curve_*_sensor_id defaultin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
    [temperature_curve_triple.yaml]
2026-08-05 Add configurable source sensors and NAN failsafe to curve triple
    Each profile now names the sensor it reads via curve_a_sensor_id,
    curve_b_sensor_id and curve_c_sensor_id. All three default to
    fancontroller_temperature, so existing configurations are unaffected: the
    generated config for the example differs only in the new globals and the
    lambda body, with no entity, name or default changes.
    Profile dispatch moves to the top of the output lambda, because which sensor
    to read now depends on which profile is active. Evaluation stays on the
    module's existing 10 s template-sensor interval rather than an on_value
    trigger, which with three possible sources would only ever fire for one.
    An unavail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
    [temperature_curve_triple.yaml]
2026-08-05 Add temperature_curve_triple_independent module and example
    Three fully independent profiles: each carries its own 5-point temperature
    axis, its own speeds, and its own source sensor. The shared-axis module keeps
    its shared axis and stays the low-entity-count option; this one costs ten
    extra numbers, 37 entities against 27.
    Independent axes are what make an inverted profile practical. A cooling curve
    whose speeds fall as temperature rises usually also needs its own temperature
    band, which the shared axis cannot give it.
    Axis validation is per profile. All three live axes are scanned every cycle,
    so an unordered axis raises the Curve Configuration Warning sensor and names
    the offending prof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
    [temperature_curve_triple_independent.yaml]
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2026-08-09 feat(fallback-mode): add HA pet blueprint and 4-port example config
    - blueprints/automation/zeroflow_fancontroller/fancontroller_supervision_pet.yaml:
    time_pattern trigger, mandatory freshness condition on the source sensor
    (catches the dominant HA-up-source-dead failure mode), presses the board's
    Supervision Pet button
    - examples/with-fallback-mode-rev-3.3.yaml: 4-port config with the single
    validated preset, api: reboot_timeout: 0s (R1)
    - Verified: ./test-examples.sh with-fallback-mode-rev-3.3 reaches
    Config phase passed, exercising the working-tree module via
    tools/localize-examples.py
    [fancontroller_supervision_pet.yaml]
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2026-08-14 feat(fallback-mode): add unit and state_class to numeric diagnostic sensors
    - Supervision Margin and Supervision Margin Min get unit_of_measurement: cycles and state_class: measurement, so Home Assistant plots them as line charts with min/mean/max long term statistics
    - Margin Low Events and Fallback Events get unit_of_measurement: events and state_class: total_increasing, so a Reset Supervision Latches press or a reboot is read as a meter reset and the accumulated total survives long term statistics
    - fallback_state_text stays a categorical text_sensor, unchanged
    - accuracy_decimals: 0 preserved on all four sensors
    - Adds a GRAPHING paragraph to the module header comment explaining why
    [fallback_mode.yaml]
2026-08-14 feat(temperature-curve-triple): make failsafe speed and hold mode configurable
    - Add curve_failsafe_speed (default "100.0") and curve_failsafe_mode
    (default "speed", or "hold") substitutions
    - Both failsafe sites (stale source sensor, non-ascending live axis) honour
    the new settings; defaults reproduce the original hard-wired 100% exactly
    - hold mode rides the last good reading past the 60 s window on the sensor
    path, and holds the last curve-derived speed on the axis path, falling
    back to curve_failsafe_speed whenever there is nothing yet to hold
    - curve_last_output / curve_last_output_valid globals track the last
    curve-derived speed, written only on the curve-derived return path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
    [temperature_curve_triple.yaml]
2026-08-14 feat(temperature-curve-triple-independent): make failsafe speed and hold mode configurable
    - Mirror the temperature_curve_triple change: curve_failsafe_speed (default
    "100.0") and curve_failsafe_mode (default "speed", or "hold")
    substitutions, honoured at both failsafe sites
    - Three axis log sites made mode-aware: the per-profile scan (fires for any
    unordered profile, active or not), the active-profile failsafe edge log,
    and the active-profile failsafe return, which is gated on the active
    profile only per the existing design
    - Stale source sensor site gets the same treatment as
    temperature_curve_triple: hold rides out the 60 s window indefinitely,
    falling back to curve_failsafe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
    [temperature_curve_triple_independent.yaml]
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2026-08-14 docs(temperature-curve-triple): correct inline comments that still claimed a fixed 100% failsafe
    The failsafe action is configurable now, so comments describing it as an
    unconditional ramp to 100% no longer match the code they sit above. Applies
    to both the stale-sensor and the non-ascending-axis sites in both modules.
    [temperature_curve_triple.yaml, temperature_curve_triple_independent.yaml]
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2026-08-26 feat(21-03): persist fan mode across reboot, re-assert before curve's first write
    - Four new restoring globals (usr_mode_fan1..4) mirror the shared,
    non-restoring usr_override_fan1..4 flags without touching the frozen
    modules/globals.yaml
    - usr_persist_modes script copies live -> persisted; called from all
    twelve sites that write a shared override flag (USR1, USR3, the
    long-press toggle, all four switches' turn_on/turn_off actions, and
    the clear-overrides button)
    - New on_boot list entry at priority -100 copies persisted -> live,
    landing well inside temperature_curve's 10s update_interval before its
    output sensor's first write
    - D-08's accepted tradeoff is left exactly as chose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
    [usr_buttons_mode.yaml]
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2026-08-26 fix(usr-buttons-mode): keep the selection alive through a mode toggle
    - Long-press branch: stop zeroing usr_selected_fan and stop()-ing the
    timeout; rearm usr_selection_timeout instead so the fan stays selected
    with a fresh full override_timeout after the toggle
    - usr_mode_flash terminal step: derive auto_led_override from the live
    selection instead of unconditionally clearing it, then hand off to
    usr_update_leds so the LEDs return to the selection display in the
    fan's new colour
    - Rewrote the usr_mode_flash_manual global's comment and the USR2
    hold header comment to describe the new behaviour
    [usr_buttons_mode.yaml]
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2026-08-26 docs(usr-buttons-mode): document the 60s flash-write window on mode persistence
    - Reboot behaviour caution now states mode changes need up to ~60s
    (the preferences component's sync interval) to reach flash before
    they survive a power cut; a cut inside that window restores the
    previous mode, masked by the fan's own restore_mode still bringing
    back the old speed, with the curve reclaiming the fan on its next
    ~10s tick
    - Tip 3 qualified to match
    - Comment-only note added at the usr_mode_fanN globals and
    usr_persist_modes in modules/usr_buttons_mode.yaml, naming the
    deferred fix (guarded global_preferences->sync()) with no
    behaviour change (verified via git diff)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
    [usr_buttons_mode.yaml]
2026-08-26 fix(usr_buttons_mode): stop the manual override switches from wiping mode on boot
    The four Fan N Manual Override template switches used the default
    restore_mode (ALWAYS_OFF). Switch::get_initial_state_with_restore_mode()
    returns a value for every mode except DISABLED, so TemplateSwitch::setup()
    called turn_off() on every boot, at setup priority HARDWARE - 2.0f. That
    fired turn_off_action, which zeroed the live usr_override_fanN flag and
    then, via usr_persist_modes, the persisted usr_mode_fanN mirror too - all
    before the module's own on_boot restore (priority -100, last) ever ran.
    The per-fan mode never survived a reboot as a result.
    Fix: restore_mode: DISABLED on all four switches. That mod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
    [usr_buttons_mode.yaml]
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
